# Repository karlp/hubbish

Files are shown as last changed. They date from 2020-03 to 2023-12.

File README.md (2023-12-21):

## Hubbish is not rubbish.

Hubbish is a USB 2.0 HS hub.  And?  It has per port power switching and overrcurrent shutoff.
And? It is designed for cascading, with 6 ports for user devices on the front, and ports
on each side for directly plugging together.  And? That's it.

## but why.gif?

Per port power switching was a goal.  Also, "this should be really simple!"
Also, to make the physical layout sensible for the desired use case.  Initially, this
project was conceived to be part of regression testing the USB stack for
[libopencm3](http://www.libopencm3.org).  The _minimal_ test setup there required 17
USB devices.  This is also why the ports are paired.  It's setup to have one port
for the DUT and one for the test driver.  They are otherwise completely independent.

That's all folks!

## Design goals
Cheap as shit, but fully functional. So, cheapest china compatible parts for everything,
but to avoid running into hub depth limits, and make config simpler, still using a
7 port hub, not attempting to cascade 4 port hubs.  Given that the original design goal requires
3 stacked hubs for 18 test ports, caascading hubs internally was not appealing.

Still, doing usb-hs on 2 layers requires fat traces and isolation to do properly, so this
setup is currently targetting jlcpcb's cheap as shit 4 layer 2313 stackup.

Oh, and design it to actually go in a case.

## Origins
This project was split out from the [libopencm3-tests](http://github.com/karlp/libopencm3-tests)
repository when it became apparent that it was it's own monster.

## Versions
### "r4" r2022-12
#### Status
Only on paper, mostly, uses a proper matched pair to "correctly" implement the auto vbus/5v switchiver. (I misunderstood the use of the matched pair, and just used two discrete transistors in overzealous BOM optimization.
TBD: fixes the pwoer good indicator on the main supply as well?
Still need to work on the "local power" portion a bit more fully? (or double check it?)

### "r3" r2022-10
#### Improvements
After a long hiatus, I decided to get back to it, and not even bother assembling the r2 boards I had gotten back.  I had already found some errors, which I can't remember entirely right now, so we just moved forward to r3:
This has a very overhauled BOM, to match JLC's assembly service, rather than just something to assemble myself by hand.
Some footprints change to suit this as well.

#### Status
This was built and assembled by JLC.  It works ok. It doesn't switch between bus powered and self powered very well, iirc.  The hub's "local power" flag isn't handled properly, and that's just my error.  The board still uses optional A-male or B-micro for the upstream USB connection, and "obviously" that should all be PD and type-C these days :)  maybe one day...
Finally, the dual colour leds chosen aren't really very good at showing two colours for low speed / full speed / high speed, particular the difference between FS and HS, which is the more interesting one.  Should revisit that, but I had enough on with this revision to not do more. The "Power Good" LED for the onboard DCDC supply doesn't work properly either, again, my error,  but not really critical.  Finally, the polarity protection FET is only rated to Vgs of 30V.  It's suggested (rightly) that this is really pushing it for a 24V design, and I should look for a better option there.

But, the 40W supply works! This is the biggest DCDC supply I'd ever made myself. (FIXME - add the picture of all the usb load testers plugged in) And not just works, it works and keeps cool, and you can deliver all that power to all 7 downstream ports, up to the limit of each of the load switches.

This design also just decided that programming the EEPROM was the _right_ thing to do, as it also lets you arrange the LEDs nicely to match the ports, and provide proper serial numbers, which are also an important part of a big cascaded port power switching design. [generatei2c.py] is a python script that generates commands for use with i2cutils to program the eeprom via the header.  I used the [i2c_tools example](https://github.com/espressif/esp-idf/tree/master/examples/peripherals/i2c/i2c_tools) on an ESP32 devboard to do this.  It's... very simplistic, but it's enough.

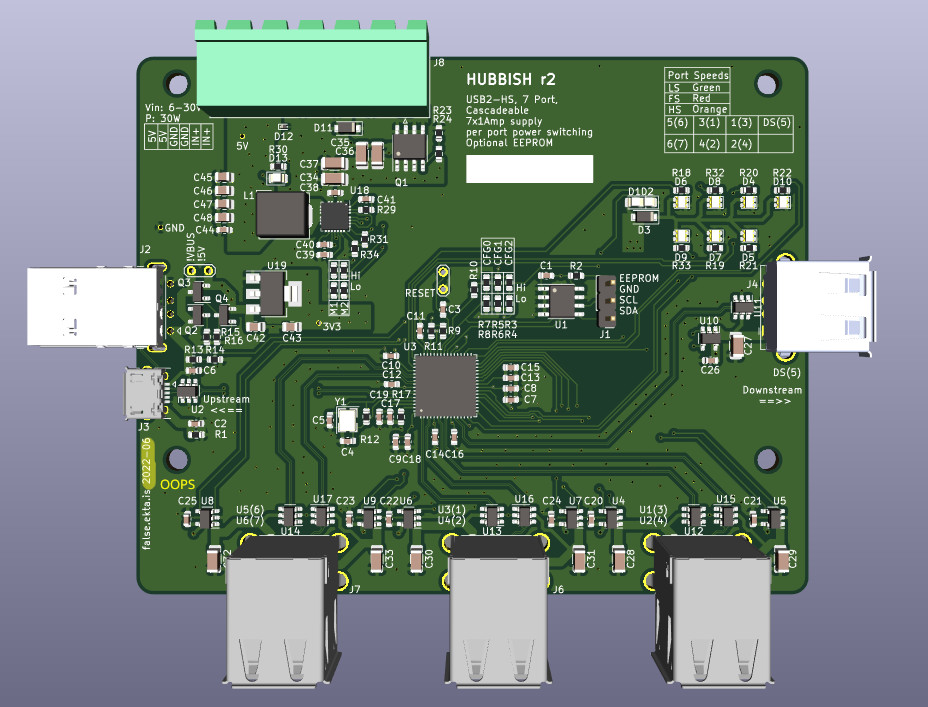
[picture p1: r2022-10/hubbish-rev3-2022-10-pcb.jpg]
r2022-10 board view
* 
* [Schematic-r3](r2022-10/hubbish-rev3-2022-10.pdf)
* Load testing all ports at once.  (I have thermal images, but have lost them... will have to retest)
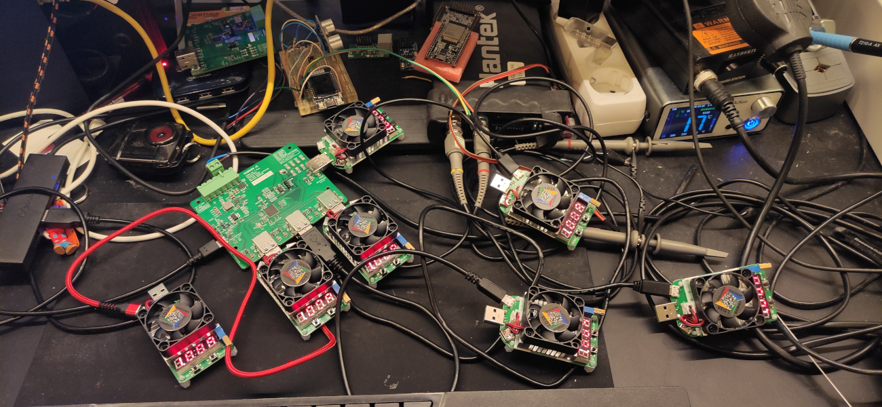
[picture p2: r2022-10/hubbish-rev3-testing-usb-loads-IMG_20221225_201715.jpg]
r2022-10-load-testing-view


### "r2" r2021-03  (lol, finished and ordered 2022-06)
#### Improvements:
Adds a 30-40ish Watt power supply.  Inductor is rated to 9A, regulator to 12A. Per port power switches are
still 1A nominal, so nominally 7x5x1 = 35W for the ports plus around .5x3.3 for the hub itself, or an extra say 2W.

Resizes to 100x80mm so cheaper manufacturing again.  We're no longer trying to find an off the shelf case.
Places like 3d craft cloud have gotten so cheap I'm going to just make a custom case and have it printed on demand.

What's it look like?
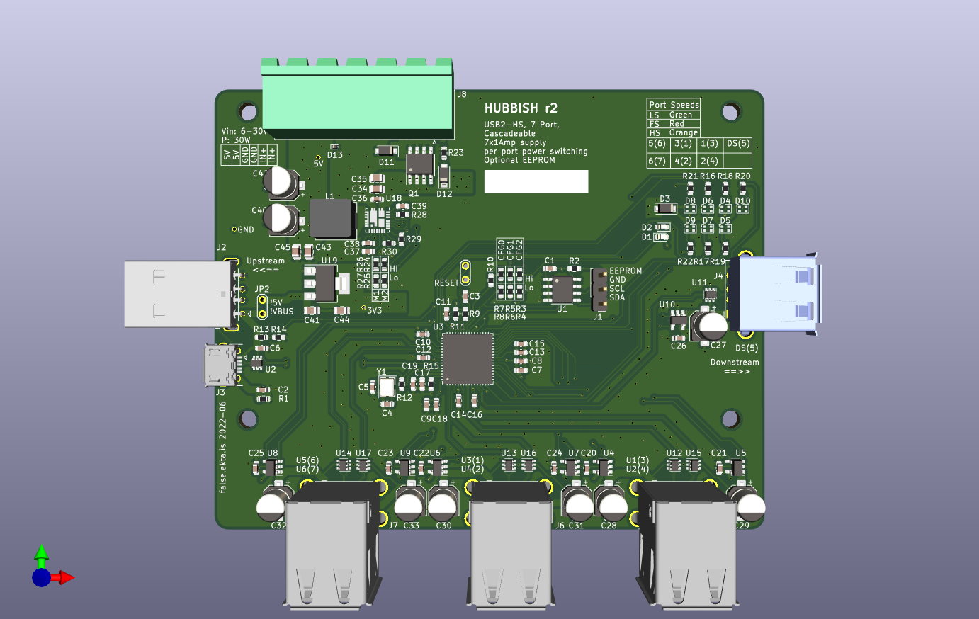
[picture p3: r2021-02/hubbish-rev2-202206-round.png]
r2022-06 board view


* [Schematic-r2](r2021-02/hubbish-rev2.pdf)

#### Bugs
This doesn't have ground connected for two caps on the 3v3 rail, and would have needed some bodge wires, but I seem to recall there being something else, to the point that I decided to not even bother assembling it, and just move on to a rev3, designed for JLC assembly.

### r2020-03
What's it look like?
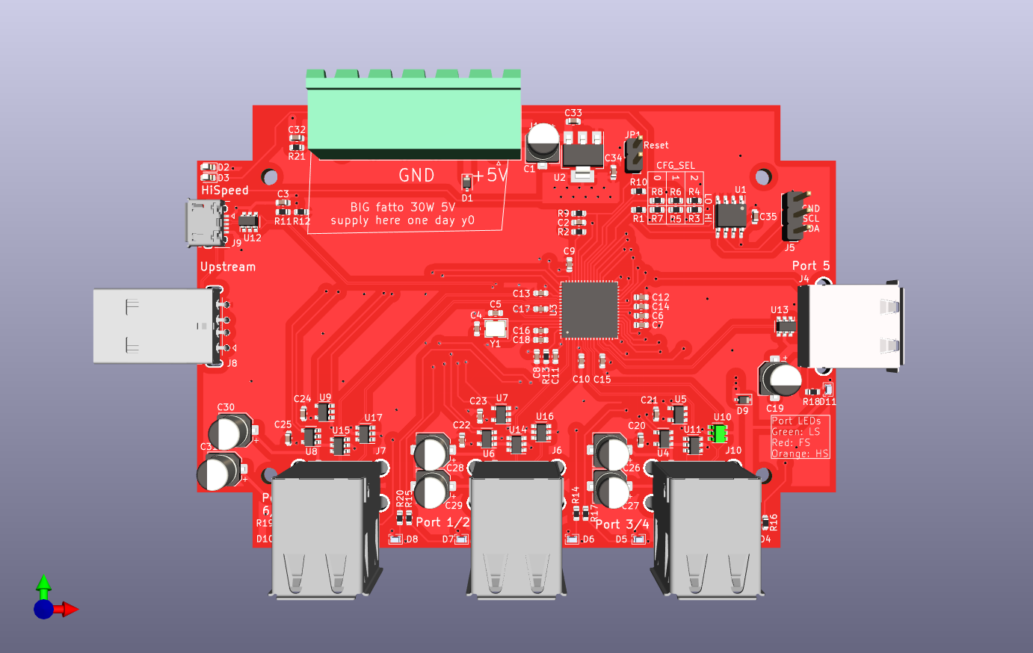
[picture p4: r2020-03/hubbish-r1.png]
r1 board view

* [Schematic-r1](r2020-03/usb-test-harness.pdf)

#### Bugs

1. Missing a serial resistor for the crystal.  Doesn't enumerate the hub without it.
1. Needs a jumper wire if yout want to actually run it as a bus powered hub for testing.
1. Port numbers are super wonky.
1. .... doesn't actually work?  I suspect I just have assembly issues, but...
1. Bigger than 100x100, which fits the Bud case nicely, and didn't matter when 4L was always just size based
   but now that jlc is doing 4L super cheap for under 100x100, this can be considered a bug
1. vertical (z axis) positioning of the usptream usb-a-male and downstream usb-a-female for chaining doesn't
   align properly.

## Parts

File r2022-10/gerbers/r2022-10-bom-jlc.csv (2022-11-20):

Comment | Designator | Footprint | JLCPCB Part #
100nF | C1,C2,C3,C8,C10,C11,C12,C14,C15,C16,C18,C19,C41,C44 | Capacitor_SMD:C_0603_1608Metric | C14663
33pF | C4,C5 | Capacitor_SMD:C_0603_1608Metric | C1663
1uF | C6,C7,C9,C13,C17,C20,C21,C22,C23,C24,C25,C26,C39,C40 | Capacitor_SMD:C_0603_1608Metric | C15849
100uF | C27,C28,C29,C30,C31,C32,C33 | Capacitor_SMD:C_1206_3216Metric | C15008
10uF/30+ | C34,C35,C36,C37 | Capacitor_SMD:C_1206_3216Metric | C13585
100nF/30+ | C38 | Capacitor_SMD:C_0603_1608Metric | C14663
10uF | C42,C43,C45,C46,C47,C48 | Capacitor_SMD:C_0805_2012Metric | C15850
HS1B | D1,D13 | LED_SMD:LED_0805_2012Metric | C84256
HS1B |  | LED_SMD:LED_0805_2012Metric | C84256
SM400x | D3 | Diode_SMD:D_SOD-123F | C64898
LTST-C195KGJRKT | D4,D5,D6,D7,D8,D9,D10 | LED_Dual:T1615_LiteOn_LTST_C195x | C125104
LTST-C195KGJRKT |  | LED_Dual:T1615_LiteOn_LTST_C195x | C125104
LTST-C195KGJRKT |  | LED_Dual:T1615_LiteOn_LTST_C195x | C125104
LTST-C195KGJRKT |  | LED_Dual:T1615_LiteOn_LTST_C195x | C125104
LTST-C195KGJRKT |  | LED_Dual:T1615_LiteOn_LTST_C195x | C125104
LTST-C195KGJRKT |  | LED_Dual:T1615_LiteOn_LTST_C195x | C125104
USB_B_Micro (up) | J3 | Connector_USB:USB_Micro-B_Amphenol_10118194-0001LF_Horizontal | C319164
USB_B_Micro (up) |  | Connector_USB:USB_Micro-B_Amphenol_10118194-0001LF_Horizontal | C319164
USB_B_Micro (up) |  | Connector_USB:USB_Micro-B_Amphenol_10118194-0001LF_Horizontal | C319164
USB_B_Micro (up) |  | Connector_USB:USB_Micro-B_Amphenol_10118194-0001LF_Horizontal | C319164
USB_B_Micro (up) |  | Connector_USB:USB_Micro-B_Amphenol_10118194-0001LF_Horizontal | C319164
1.5uH | L1 | Inductor_SMD:L_Chilisin_BMRx00060630 | C329386
HSM6115 | Q1 | Package_SO:SOIC-8_3.9x4.9mm_P1.27mm | C700986
S8550 | Q2,Q4 | Package_TO_SOT_SMD:SOT-23 | C105432
AO3401A | Q3 | Package_TO_SOT_SMD:SOT-23 | C15127
330 | R1,R10,R18,R19,R20,R21,R22,R30,R32,R33 | Resistor_SMD:R_0603_1608Metric | C23138
10k | R2,R4,R5,R7,R11,R15,R16,R23,R34 | Resistor_SMD:R_0603_1608Metric | C25804
100k | R9,R13,R14,R26 | Resistor_SMD:R_0603_1608Metric | C25803
1M | R12 | Resistor_SMD:R_0603_1608Metric | C22935
12k | R17 | Resistor_SMD:R_0603_1608Metric | C22790
20k | R24 | Resistor_SMD:R_0603_1608Metric | C4184
20k |  | Resistor_SMD:R_0603_1608Metric | C4184
510k | R28 | Resistor_SMD:R_0603_1608Metric | C23192
0 | R29 | Resistor_SMD:R_0603_1608Metric | C21189
75k | R31 | Resistor_SMD:R_0603_1608Metric | C23242
75k |  | Resistor_SMD:R_0603_1608Metric | C23242
2k i2c eeprom | U1 | Package_SO:SOIC-8_3.9x4.9mm_P1.27mm | C7562
NUP4202 | U2,U11,U12,U13,U14,U15,U16,U17 | Package_TO_SOT_SMD:SOT-23-6 | C85364
USB2517 | U3 | Package_DFN_QFN:QFN-64-1EP_9x9mm_P0.5mm_EP4.7x4.7mm_ThermalVias | C626667
APL3511C | U4,U5,U6,U7,U8,U9,U10 | Package_TO_SOT_SMD:SOT-23-5 | C211404
SiC437AED | U18 | Package_DFN_QFN:Vishay_MLP-44L_4x4 | C2071432
AMS1117-33 | U19 | Package_TO_SOT_SMD:SOT-223-3_TabPin2 | C6186
24MHz | Y1 | Crystal:Crystal_SMD_3225-4Pin_3.2x2.5mm | C70590

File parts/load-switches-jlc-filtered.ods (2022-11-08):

Part | jlc basic | jlc extended | enable level | overcurrent | iset | max I | package | pincompat | lcsc number | jlc price | notes
AIC6163-1GV5TR | no | yes | high | low | no | 1 | Sot23-5 | no
AP22802AW5-7 | no | yes | high | low | no | 2 | Sot23-5 | yes | C211404 | 0.166
APL3512ABI-TRG | no | yes | high | no | no | 2 | So23-5
APL3553ABI-TRG | no | yes | high | low | no | 2 | Sot23-5 | yes | C691406 | 0.229
bd2232G | no | yes | high | low | no | 1.3 | ssop5 | not at all | C308588
bd2233g | no |  | low | low | no | 1.3 | ssop5
DIO7002AST5 | no | yes | high | no | yes | 2.5 | Sot23-4
DIO7003HDST5 | no | yes | high | low | no | 1.5 | Sot23-5 | yes | C403841 | 0.218
DIO7003LBST5 | no | yes | low | low | no | 0.7 | Sot23-5
lp5208b5 | no | yes | high | no | no | 1.2 | Sot23-5
LPW5209AB5F | no | yes | high | no | yes | 2.1 | Sot23-5
max40200 | no | yes | high | no | no | 1.2 | Sot23-5 | no
MT9700 | no | yes | high | no | yes | 2 | Sot23-5
nct3521 | no | yes | high | no | no | 2 | Sot23-5
Ry2121 | no | yes | high | no | yes | 2 | Sot23-5 |  |  | 0.074 | (very cheap though)
SGM2554AYN5G/TR | no | yes | high | no | no | 2 | Sot23-5
SIP32431DR3-T1GE3 | no | yes | high | no | no | 1.2 | Sc70-6
st890 | no | yes | low | low | yes | 1.2 | so8
sy6280aaac | no | yes | high | no | yes | 2 | Sot23-5
sy6280aac | no | yes | high | no | yes | 2 | Sot23-5
sy6288c3aac | no | yes | high | low | no | 1.5 | Sot23-5 | yes | C207612 | 0.201
sy6288caac | no | yes | high | low | no | 2 | Sot23-5 | yes | C111830 | 0.167
TMI6262AL | no | yes | low | no | yes | 2.4
TPS2051BDBVR | no | yes | high | low | no | 0.5 | Sot23-5 | yes |  | 0.385
TPS2065CDBVR | no | yes | high | low | no | 1 | Sot23-5 | yes | C353882 | 0.609
TPS2065DBVR | no | yes | high | low | no | 1 | Sot23-5 | yes | C133792 | 0.935 | more expensive? Lower rdsON
TPS2069CDBVR | no | yes | high | low | no | 1.5 | Sot23-5 | yes | C181752 | 0.395 | very good stock
TPS22810DBVR | no | yes | high | no | no | 2 | Sot-23-6
tps2553dbvr | no | yes | high | low | yes | 1.5 | Sot-23-6 | no | C55266
Lp5209b5f-21 | no | yes | high | no | yes | 2.1 | Sot23-5 |  | C517266 | 0.124
SD00HA | no | yes | high | no | yes | 2 | Sot23-5

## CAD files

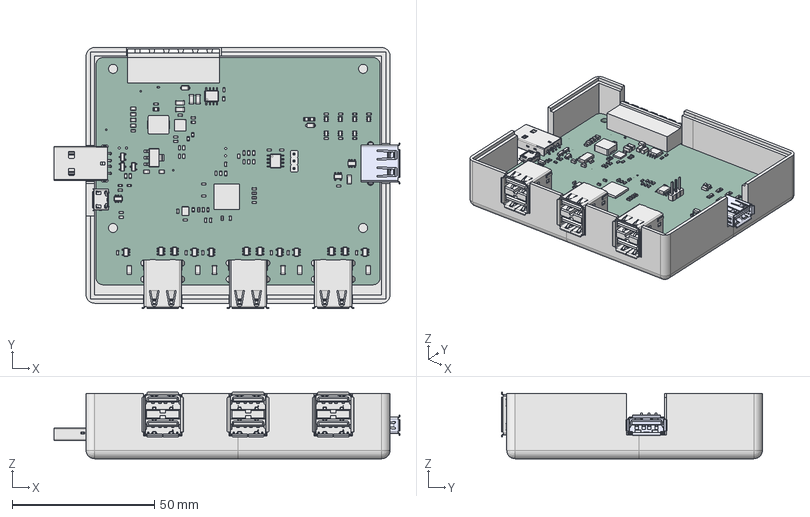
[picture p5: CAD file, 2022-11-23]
cases/hubbish-r3-202211-5.FCStd
121.8 x 91.8 x 23.4 mm
lower2
r2022-10 PCB

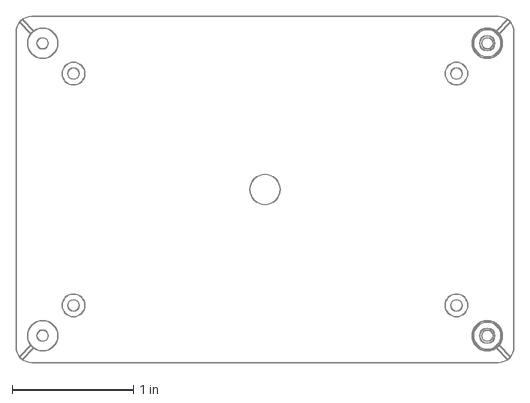
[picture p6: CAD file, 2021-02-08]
parts/enclosures/bud-pcb-guide.dxf
4.11 x 2.86 in

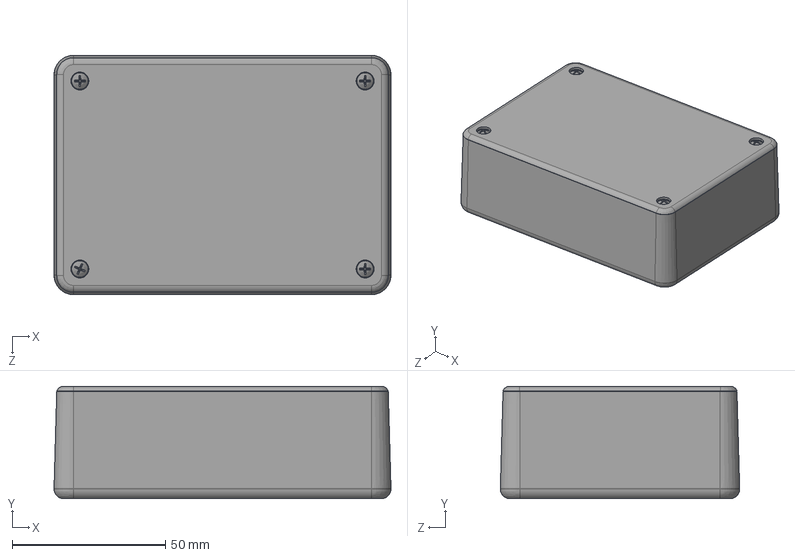
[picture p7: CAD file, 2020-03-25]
parts/enclosures/bud-CU-388.STEP
110.0 x 36.7 x 78.1 mm
387-SCR x 4
388-B
388-C

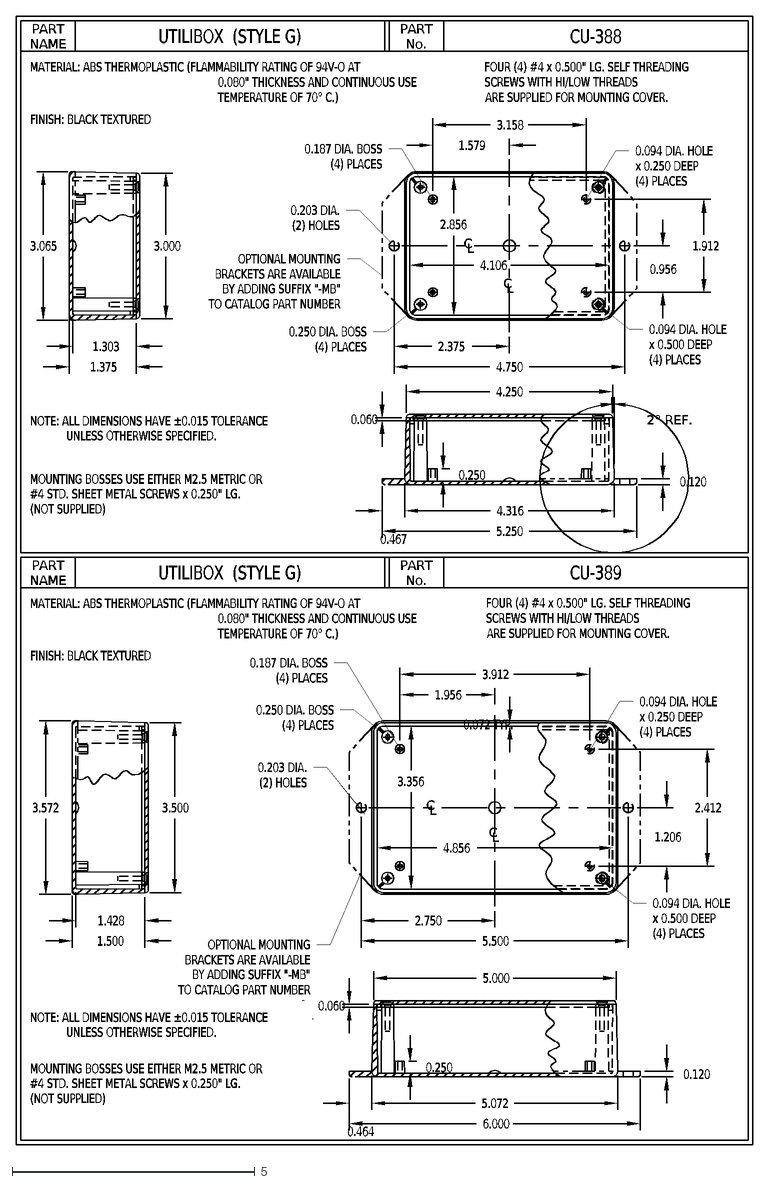
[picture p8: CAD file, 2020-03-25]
parts/enclosures/bud-hb388.dxf
FOUR (4) #4 x 0.500" LG. SELF THREADING
SCREWS WITH HI/LOW THREADS
%%@
%%!
ARE SUPPLIED FOR MOUNTING COVER.
NAME
PART
No.
UTILIBOX (STYLE G)
CU-388
MATERIAL: ABS THERMOPLASTIC (FLAMMABILITY RATING OF 94V-O AT
0.080" THICKNESS AND CONTINUOUS USE
TEMPERATURE OF 70° C.)
FINISH: BLACK TEXTURED
CU-389
0.060
4.250
3.000
1.303
1.375
3.065
1.579
3.158
C
L
0.094 DIA. HOLE
x 0.250 DEEP
(4) PLACES
0.187 DIA. BOSS
4.316
0.956
1.912
0.250
0.120
5.250
0.467
0.203 DIA.
(2) HOLES
4.750
2.375
OPTIONAL MOUNTING
BRACKETS ARE AVAILABLE
BY ADDING SUFFIX "-MB"
TO CATALOG PART NUMBER
x 0.500 DEEP
0.250 DIA. BOSS
4.106
2.856
2° REF.
5.000
0.072 TYP.
3.500
1.428
1.500
5.072
3.572
1.206
2.412
1.956
3.912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

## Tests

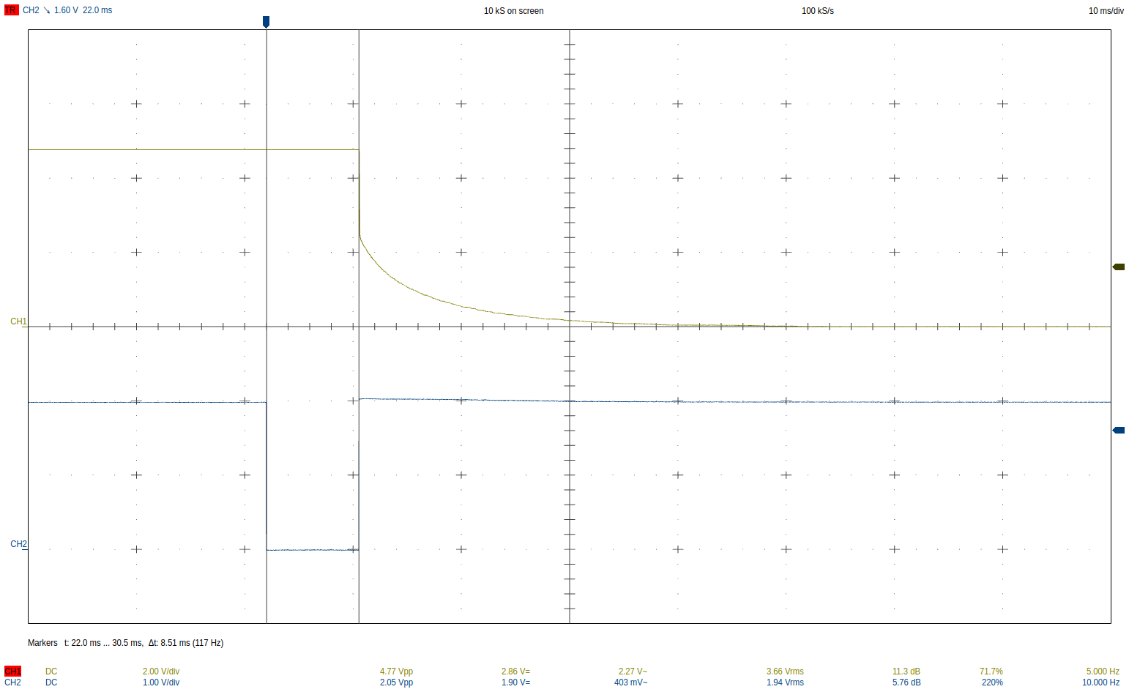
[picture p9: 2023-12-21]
testing/20221206_22414-vout-vs-flag-ocp.png

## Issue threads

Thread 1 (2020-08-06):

doesn't support self powered

karlp, 2020-08-06:
vbus is sensed, but that's it, set it up as self powered only for some reason

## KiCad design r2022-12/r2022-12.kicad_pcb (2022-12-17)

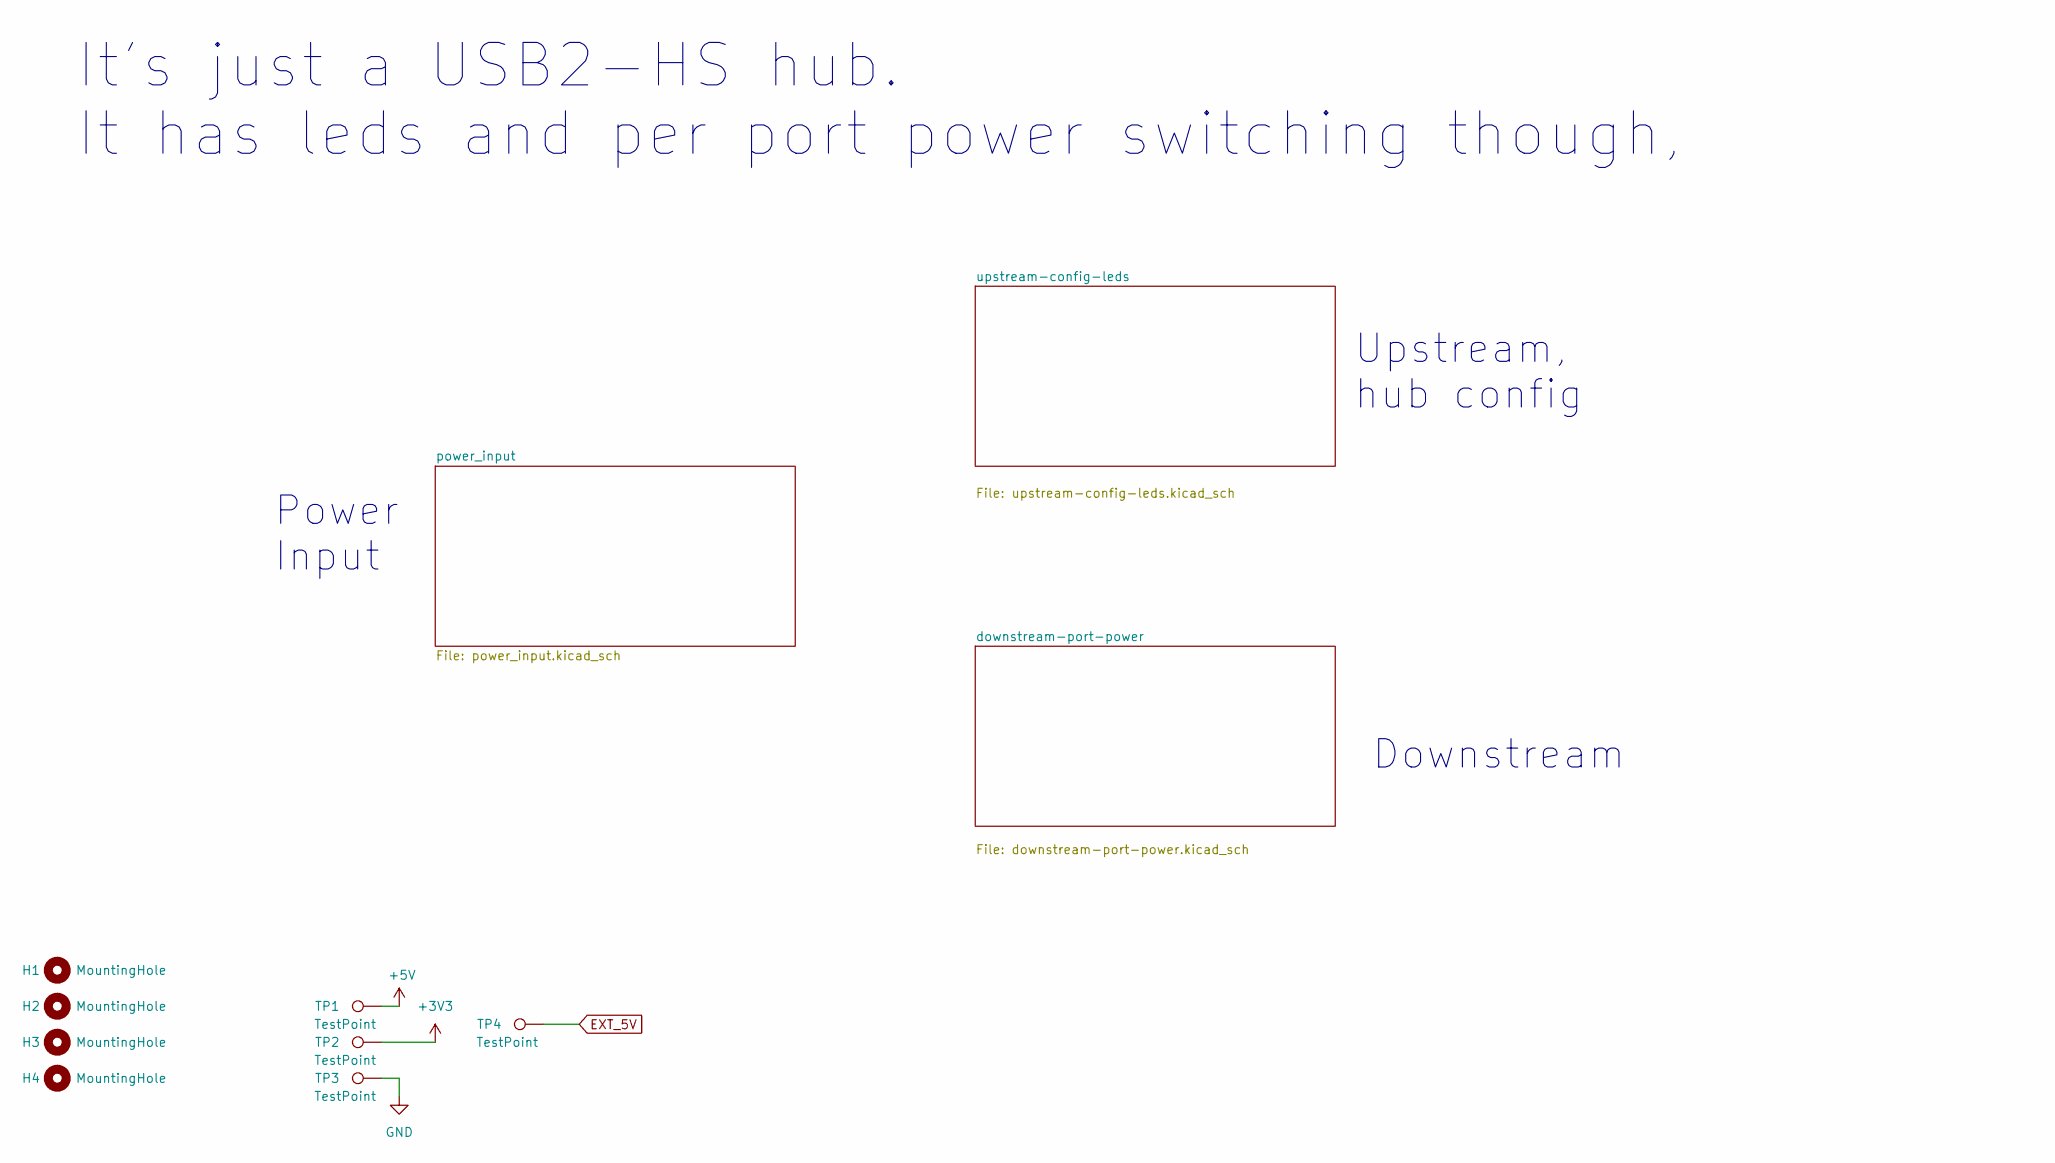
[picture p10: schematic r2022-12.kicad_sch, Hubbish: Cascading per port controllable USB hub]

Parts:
H1, H2, H3, H4: MountingHole; MountingHole_3.2mm_M3
TP1, TP2, TP3, TP4: TestPoint; TestPoint_Plated_Hole_0.6_D0.8mm

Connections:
+3V3: TP2.1; also elsewhere on the board
+5V: TP1.1; also elsewhere on the board
EXT_5V: TP4.1; also elsewhere on the board
GND: TP3.1; also elsewhere on the board

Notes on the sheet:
Upstream, hub config
Downstream
Power Input
It's just a USB2-HS hub. It has leds and per port power switching though,

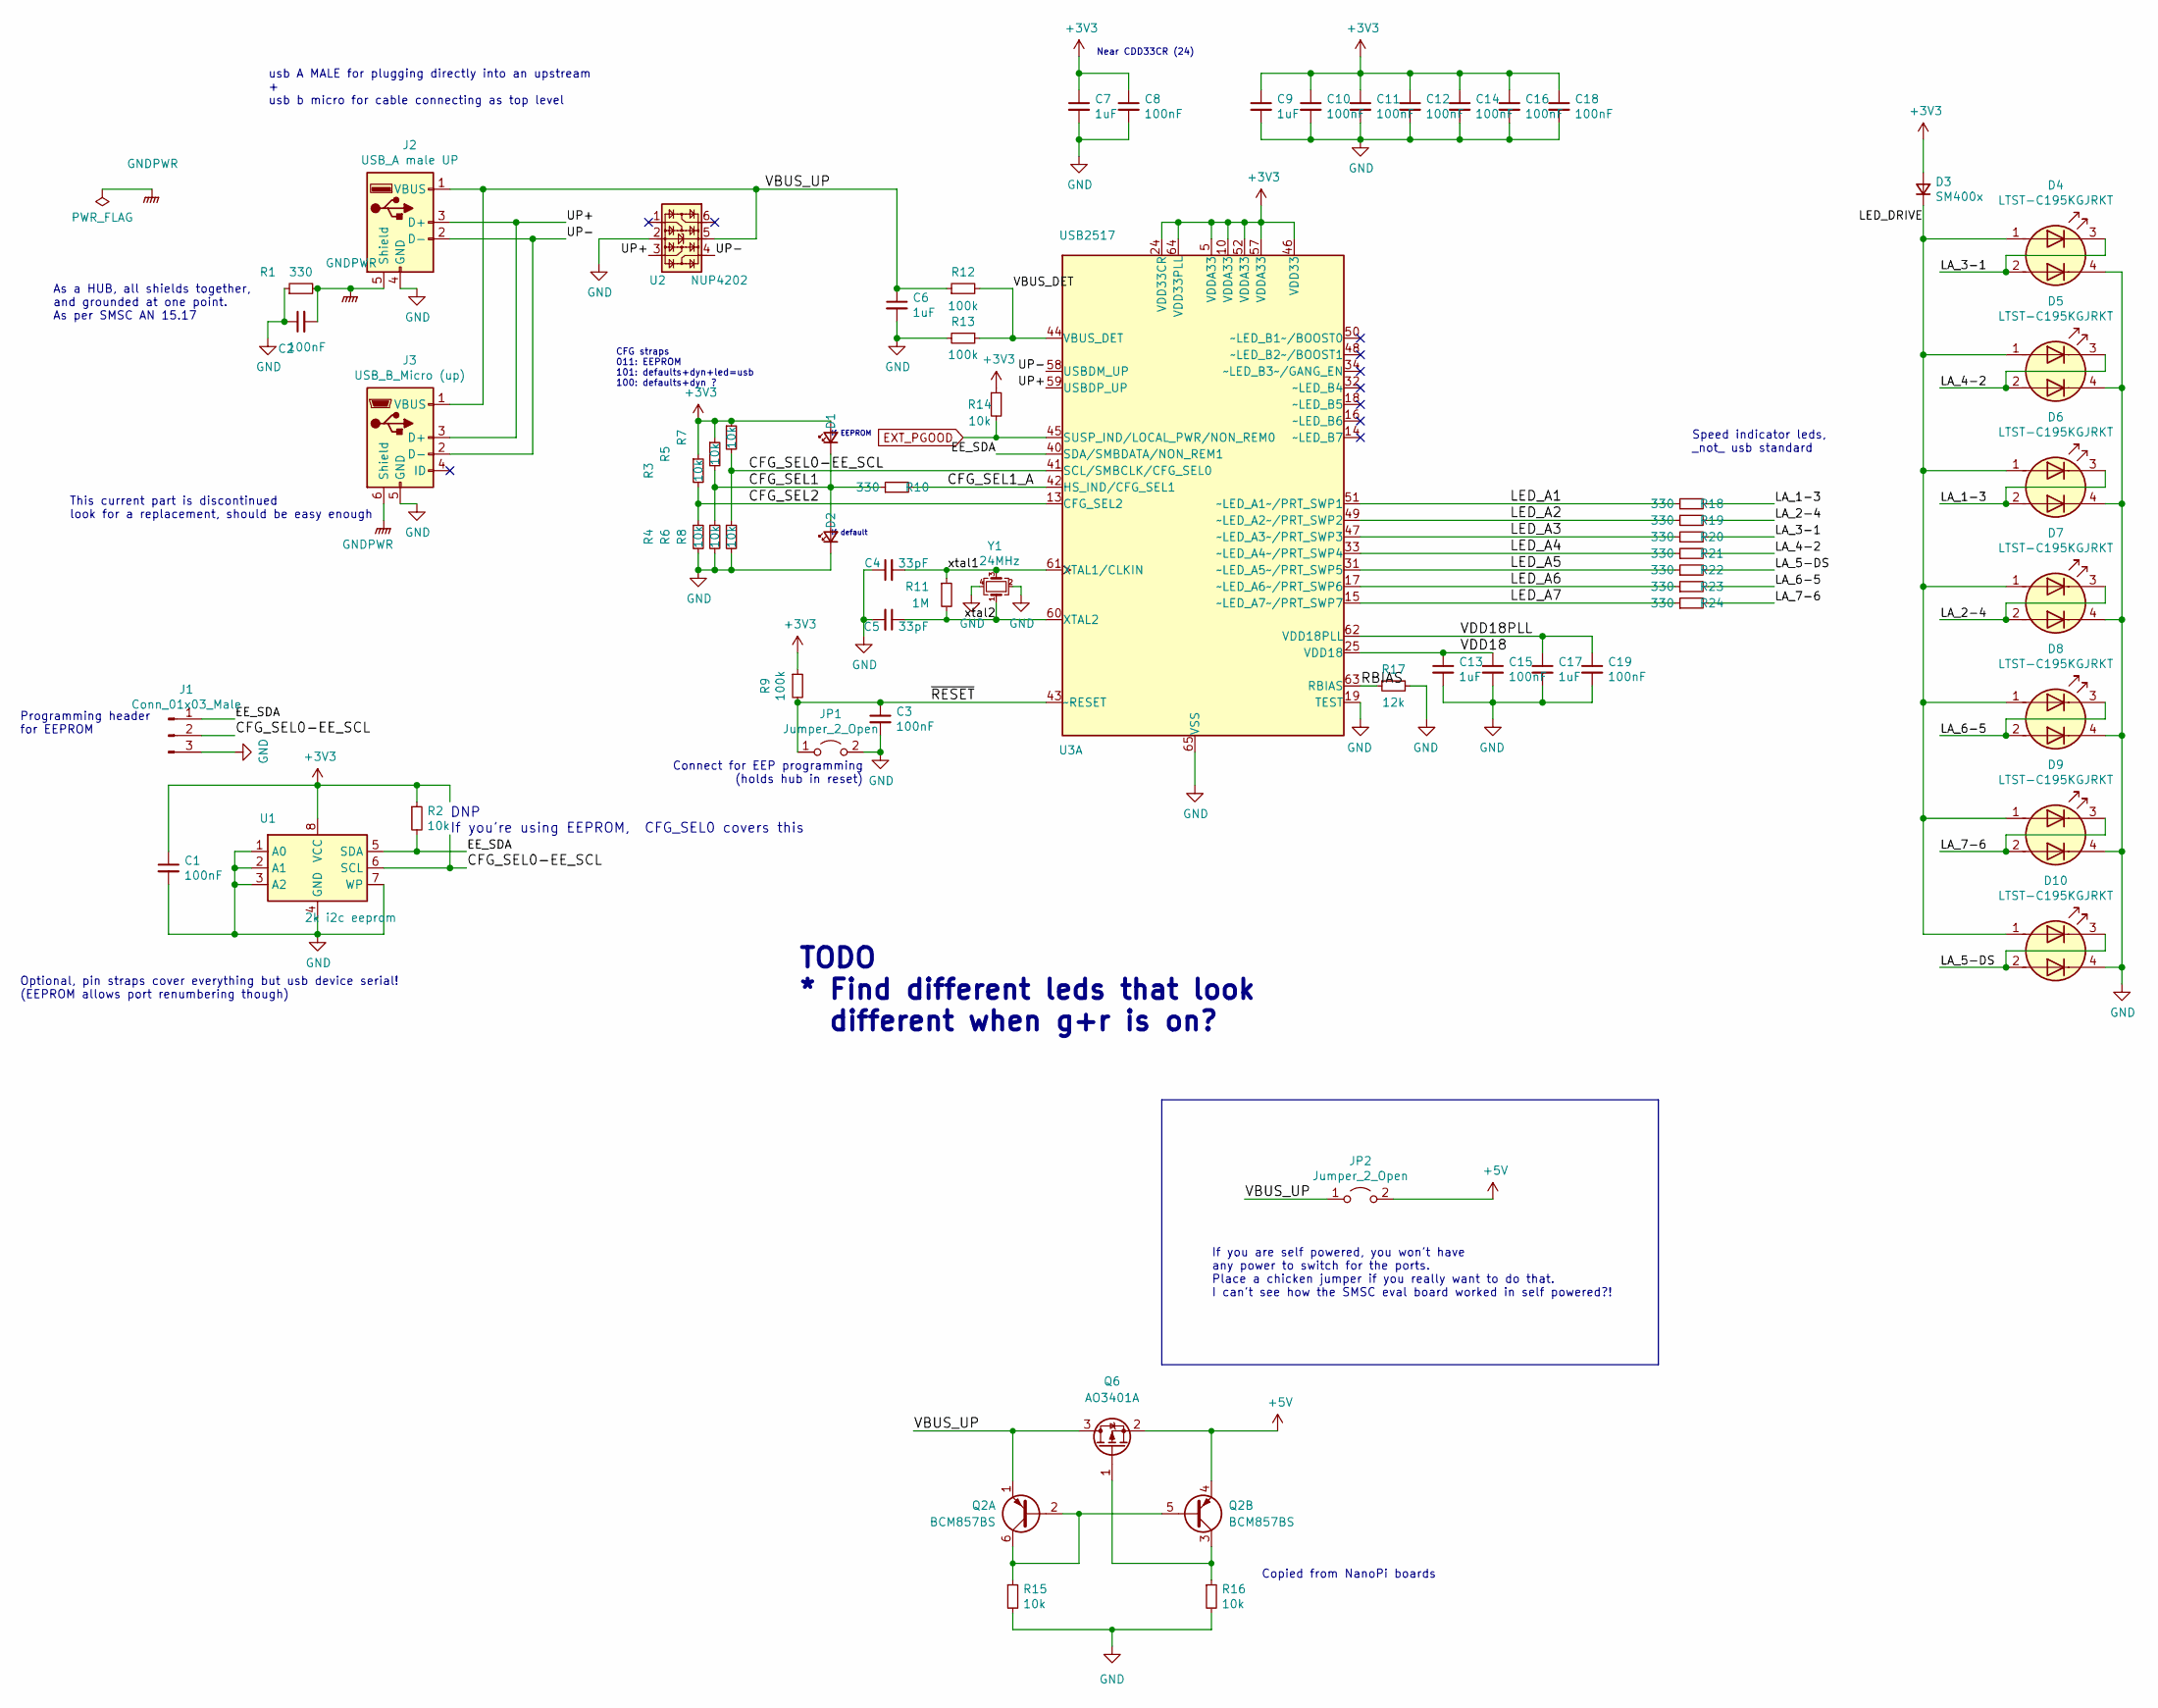
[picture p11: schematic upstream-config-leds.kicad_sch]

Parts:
C1, C2, C3, C8, C10, C11, C12, C14, C15, C16, C18, C19: 100nF; C_0603_1608Metric; MPN CC0603KRX7R9BB104; lcsc# C14663
C4, C5: 33pF; C_0603_1608Metric; MPN CL10C330JB8NNNC; jlc-basic 1
C6, C7, C9, C13, C17: 1uF; C_0603_1608Metric; MPN CL10A105KB8NNNC; jlc-basic 1
D1: HS1B; LED_0805_2012Metric; MPN NCD0805R1; jlc-basic 1
D2: HS1A; LED_0805_2012Metric; MPN NCD0805R1; jlc-basic 1
D3: SM400x; D_SOD-123F; MPN SM4007PL; jlc-basic 1
D4, D5, D6, D7, D8, D9, D10: LTST-C195KGJRKT; T1615_LiteOn_LTST_C195x; MPN LTST-C195KGJRKT; jlc-basic 0
J1: Conn_01x03_Male; PinHeader_1x03_P2.54mm_Vertical
J2: USB_A male UP; USB_A_Plug_SOFNG_USB-05; MPN SOFNG USB-05
J3: USB_B_Micro (up); USB_Micro-B_Amphenol_10118194-0001LF_Horizontal; MPN U254-051T-4BH23-S2B; jlc-basic 0
JP1, JP2: Jumper_2_Open; TestPoint_2Pads_Pitch2.54mm_Drill0.8mm
Q2: BCM857BS; SOT-363_SC-70-6; MPN BCM857BS-7-F; jlc-basic 0
Q6: AO3401A; SOT-23; MPN AO3401A; jlc-basic 1
R1, R10, R18, R19, R20, R21, R22, R23, R24: 330; R_0603_1608Metric; MPN 0603WAF3300T5E; jlc-basic 1
R2, R3, R4, R5, R6, R7, R8, R14, R15, R16: 10k; R_0603_1608Metric; MPN 0603WAF1002T5E; jlc-basic 1
R9, R12, R13: 100k; R_0603_1608Metric; MPN 0603WAF1003T5E; jlc-basic 1
R11: 1M; R_0603_1608Metric; MPN 0603WAF1004T5E; lcsc# C22935
R17: 12k; R_0603_1608Metric; MPN 0603WAF1202T5E; jlc-basic 1
U1: 2k i2c eeprom; SOIC-8_3.9x4.9mm_P1.27mm; MPN M24C02-WMN6TP; jlc-basic 1
U2: NUP4202; SOT-23-6; MPN SRV05-4-P-T7; jlc-basic 1
U3: USB2517; QFN-64-1EP_9x9mm_P0.5mm_EP4.7x4.7mm_ThermalVias; MPN USB2517I-JZX-TR; jlc-basic 0
Y1: 24MHz; Crystal_SMD_3225-4Pin_3.2x2.5mm; MPN X322524MOB4SI; jlc-basic 0

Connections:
+3V3: C1.1, C7.1, C8.1, C9.1, C10.1, C11.1, C12.1, C14.1, C16.1, C18.1, D1.2 (A), D3.2 (A), R2.1, R3.1, R5.1, R7.1, R9.1, R14.1, U1.8 (VCC), U3.5 (VDDA33), U3.10 (VDDA33), U3.24 (VDD33CR), U3.46 (VDD33), U3.52 (VDDA33), U3.57 (VDDA33), U3.64 (VDD33PLL); also elsewhere on the board
+5V: JP2.2 (B), Q2.4 (E2), Q6.2 (S); also elsewhere on the board
/upstream-config-leds/CFG_SEL0-EE_SCL: J1.2, R7.2, R8.1, U1.6 (SCL), U3.41 (SCL/SMBCLK/CFG_SEL0)
/upstream-config-leds/CFG_SEL1: D1.1 (K), D2.2 (A), R5.2, R6.1, R10.1
/upstream-config-leds/CFG_SEL1_A: R10.2, U3.42 (HS_IND/CFG_SEL1)
/upstream-config-leds/CFG_SEL2: R3.2, R4.1, U3.13 (CFG_SEL2)
/upstream-config-leds/EE_SDA: J1.1, R2.2, U1.5 (SDA), U3.40 (SDA/SMBDATA/NON_REM1)
/upstream-config-leds/LA_1-3: D6.2 (A2), D6.3 (K1), R18.2
/upstream-config-leds/LA_2-4: D7.2 (A2), D7.3 (K1), R19.2
/upstream-config-leds/LA_3-1: D4.2 (A2), D4.3 (K1), R20.2
/upstream-config-leds/LA_4-2: D5.2 (A2), D5.3 (K1), R21.2
/upstream-config-leds/LA_5-DS: D10.2 (A2), D10.3 (K1), R22.2
/upstream-config-leds/LA_6-5: D8.2 (A2), D8.3 (K1), R23.2
/upstream-config-leds/LA_7-6: D9.2 (A2), D9.3 (K1), R24.2
/upstream-config-leds/LED_A1: R18.1, U3.51 (~LED_A1~/PRT_SWP1)
/upstream-config-leds/LED_A2: R19.1, U3.49 (~LED_A2~/PRT_SWP2)
/upstream-config-leds/LED_A3: R20.1, U3.47 (~LED_A3~/PRT_SWP3)
/upstream-config-leds/LED_A4: R21.1, U3.33 (~LED_A4~/PRT_SWP4)
/upstream-config-leds/LED_A5: R22.1, U3.31 (~LED_A5~/PRT_SWP5)
/upstream-config-leds/LED_A6: R23.1, U3.17 (~LED_A6~/PRT_SWP6)
/upstream-config-leds/LED_A7: R24.1, U3.15 (~LED_A7~/PRT_SWP7)
/upstream-config-leds/LED_DRIVE: D3.1 (K), D4.1 (A1), D5.1 (A1), D6.1 (A1), D7.1 (A1), D8.1 (A1), D9.1 (A1), D10.1 (A1)
/upstream-config-leds/RBIAS: R17.1, U3.63 (RBIAS)
/upstream-config-leds/UP+: J2.3 (D+), J3.3 (D+), U2.3, U3.59 (USBDP_UP)
/upstream-config-leds/UP-: J2.2 (D-), J3.2 (D-), U2.4, U3.58 (USBDM_UP)
/upstream-config-leds/VBUS_DET: R12.2, R13.1, U3.44 (VBUS_DET)
/upstream-config-leds/VBUS_UP: C6.1, J2.1 (VBUS), J3.1 (VBUS), JP2.1 (A), Q2.1 (E1), Q6.3 (D), R12.1, U2.5
/upstream-config-leds/VDD18: C13.1, C15.1, U3.25 (VDD18)
/upstream-config-leds/VDD18PLL: C17.1, C19.1, U3.62 (VDD18PLL)
/upstream-config-leds/xtal1: C4.2, R11.1, U3.61 (XTAL1/CLKIN), Y1.3
/upstream-config-leds/xtal2: C5.1, R11.2, U3.60 (XTAL2), Y1.1
/upstream-config-leds/~RESET: C3.1, JP1.1 (A), R9.2, U3.43 (~RESET)
EXT_PGOOD: R14.2, U3.45 (SUSP_IND/LOCAL_PWR/NON_REM0); also elsewhere on the board
GND: C1.2, C2.1, C3.2, C4.1, C5.2, C6.2, C7.2, C8.2, C9.2, C10.2, C11.2, C12.2, C13.2, C14.2, C15.2, C16.2, C17.2, C18.2, C19.2, D2.1 (K), D4.4 (K2), D5.4 (K2), D6.4 (K2), D7.4 (K2), D8.4 (K2), D9.4 (K2), D10.4 (K2), J1.3, J2.4 (GND), J3.5 (GND), JP1.2 (B), R1.1, R4.2, R6.2, R8.2, R13.2, R15.2, R16.2, R17.2, U1.1 (A0), U1.2 (A1), U1.3 (A2), U1.4 (GND), U1.7 (WP), U2.2, U3.19 (TEST), U3.65 (VSS), Y1.2, Y1.4; also elsewhere on the board
GNDPWR: C2.2, J2.5 (Shield), J3.6 (Shield), R1.2; also elsewhere on the board
unnamed: Q2.3 (C2), Q6.1 (G), R16.1
unnamed: Q2.2 (B1), Q2.5 (B2), Q2.6 (C1), R15.1

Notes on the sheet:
If default
If EEPROM
usb A MALE for plugging directly into an upstream + usb b micro for cable connecting as top level
DNP If you're using EEPROM, CFG_SEL0 covers this
CFG straps 011: EEPROM 101: defaults+dyn+led=usb 100: defaults+dyn ?
Copied from NanoPi boards
TODO * Find different leds that look different when g+r is on?
Speed indicator leds, _not_ usb standard
If you are self powered, you won't have any power to switch for the ports. Place a chicken jumper if you really want to do that. I can't see how the SMSC eval board worked in self powered?!
Near CDD33CR (24)
As a HUB, all shields together, and grounded at one point. As per SMSC AN 15.17
Optional, pin straps cover everything but usb device serial! (EEPROM allows port renumbering though)
Programming header for EEPROM
Connect for EEP programming (holds hub in reset)
This current part is discontinued look for a replacement, should be easy enough

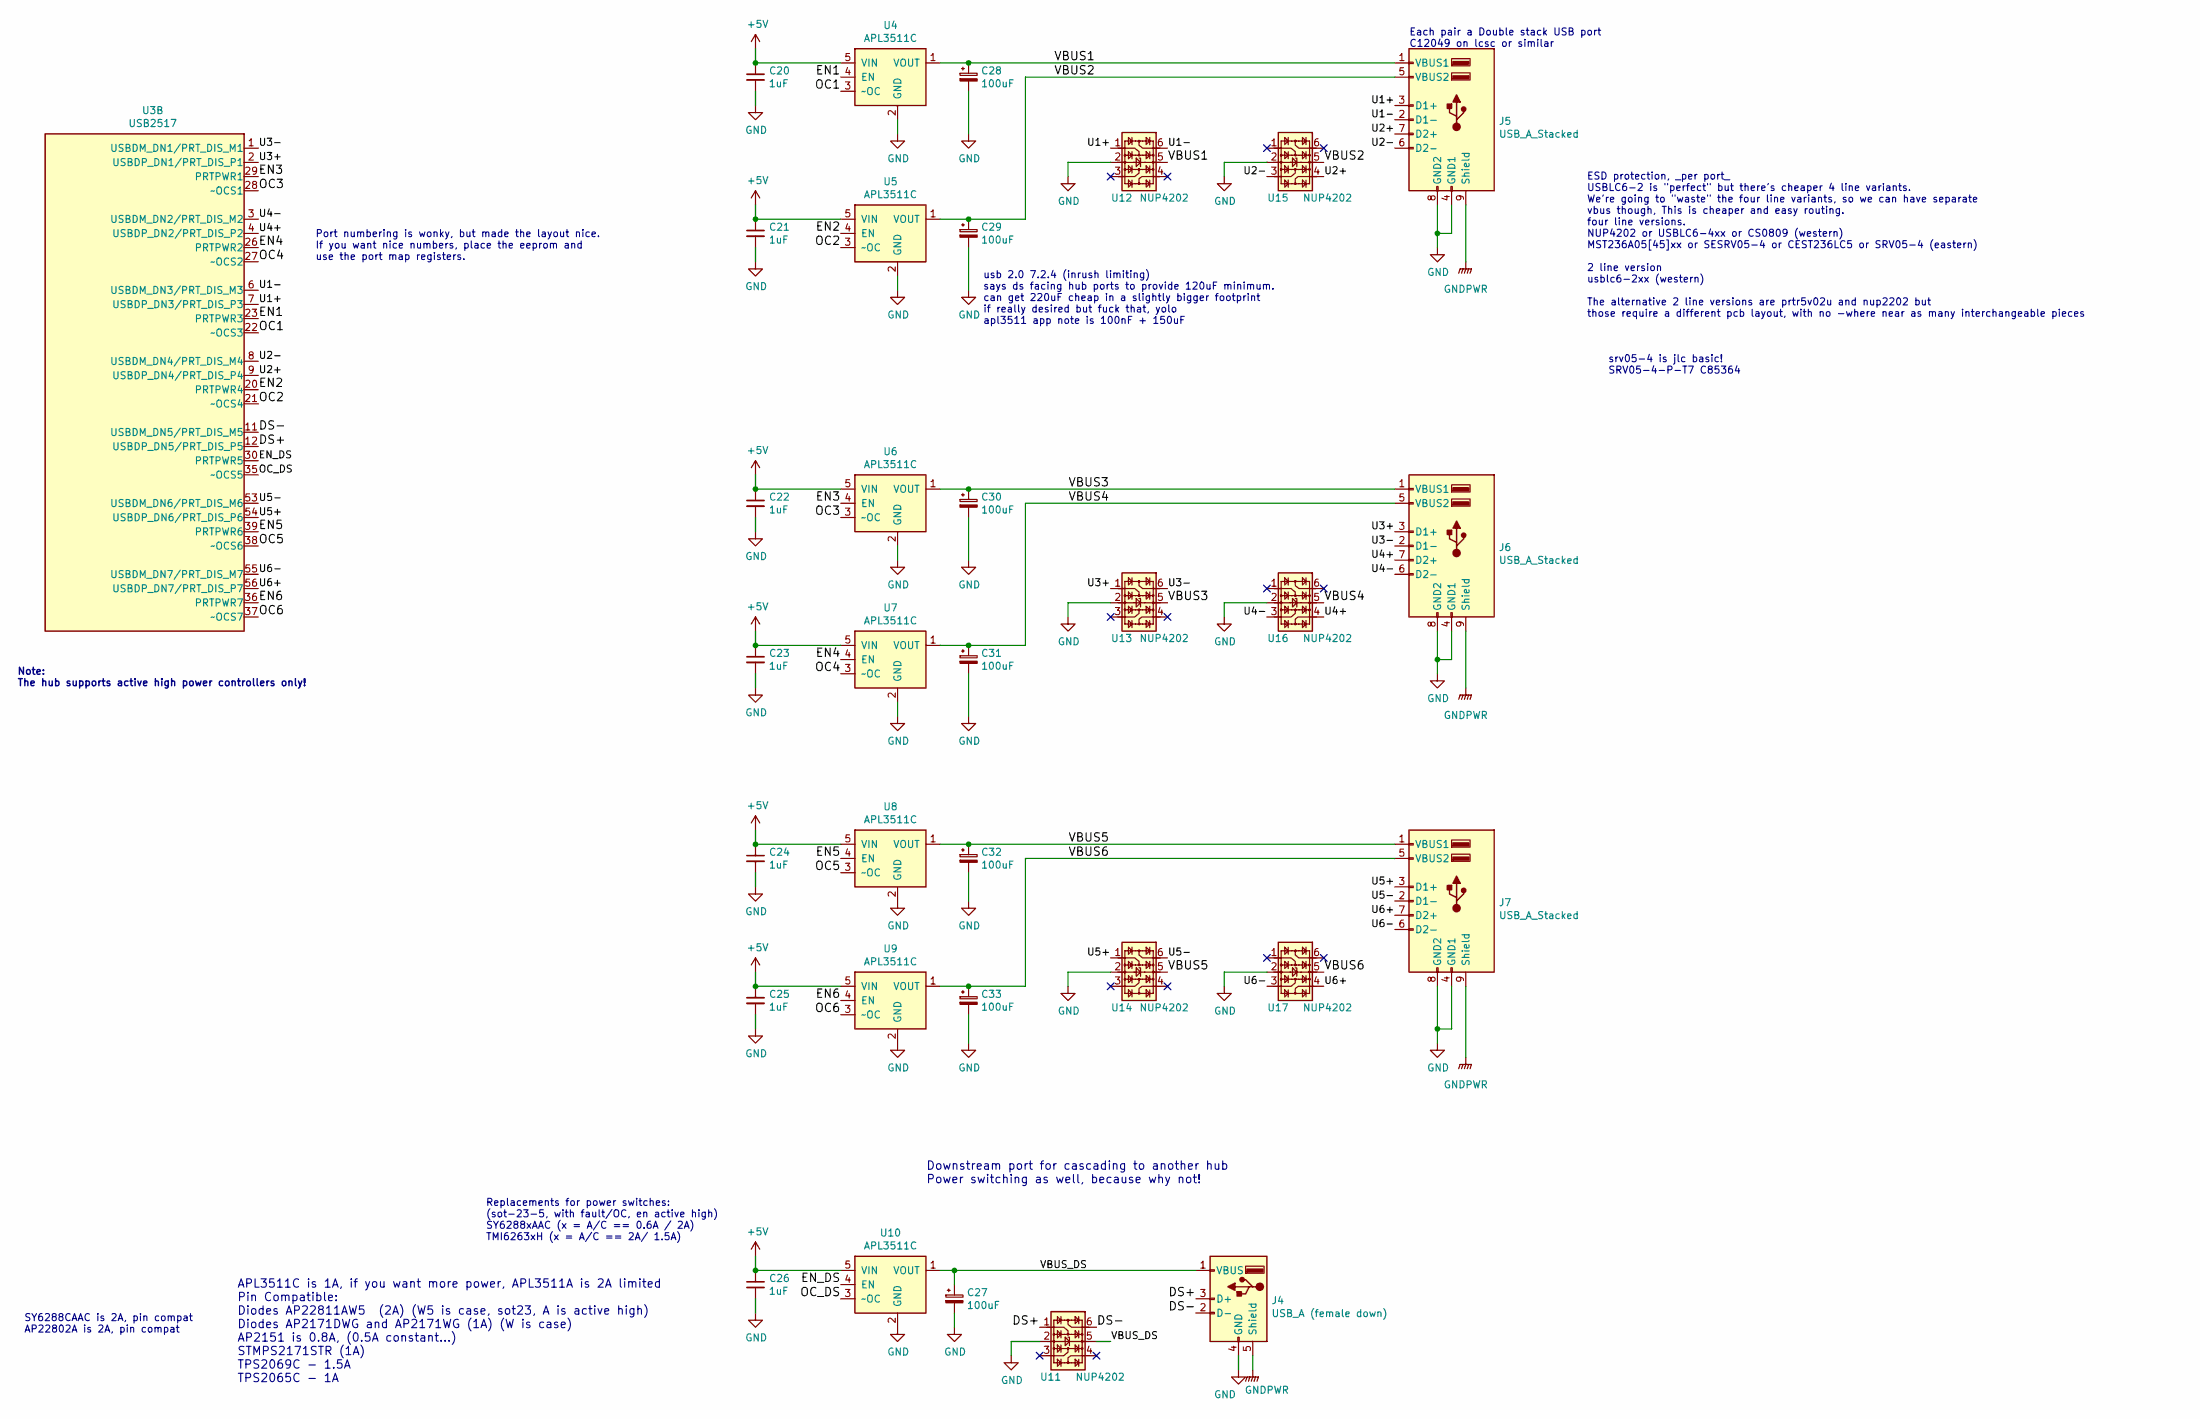
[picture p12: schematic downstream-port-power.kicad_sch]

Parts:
C20, C21, C22, C23, C24, C25, C26: 1uF; C_0603_1608Metric; MPN CL10A105KB8NNNC; jlc-basic 1
C27, C28, C29, C30, C31, C32, C33: 100uF; C_1206_3216Metric; MPN CL31A107MQHNNNE; jlc-basic 1
J4: USB_A (female down); USB_A_Stewart_SS-52100-001_Horizontal; MPN 902-141A1011D10100; jlc-basic 0
J5, J6, J7: USB_A_Stacked; USB_A_Wuerth_61400826021_Horizontal_Stacked; MPN 907-111A1012D10200; jlc-basic 0
U3: USB2517; QFN-64-1EP_9x9mm_P0.5mm_EP4.7x4.7mm_ThermalVias; MPN USB2517I-JZX-TR; jlc-basic 0
U4, U5, U6, U7, U8, U9, U10: APL3511C; SOT-23-5; MPN AP22802AW5-7; jlc-basic 0
U11, U12, U13, U14, U15, U16, U17: NUP4202; SOT-23-6; MPN SRV05-4-P-T7; jlc-basic 1

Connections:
+5V: C20.1, C21.1, C22.1, C23.1, C24.1, C25.1, C26.1, U4.5 (VIN), U5.5 (VIN), U6.5 (VIN), U7.5 (VIN), U8.5 (VIN), U9.5 (VIN), U10.5 (VIN); also elsewhere on the board
/downstream-port-power/DS+: J4.3 (D+), U3.12 (USBDP_DN5/PRT_DIS_P5), U11.1
/downstream-port-power/DS-: J4.2 (D-), U3.11 (USBDM_DN5/PRT_DIS_M5), U11.6
/downstream-port-power/EN1: U3.23 (PRTPWR3), U4.4 (EN)
/downstream-port-power/EN2: U3.20 (PRTPWR4), U5.4 (EN)
/downstream-port-power/EN3: U3.29 (PRTPWR1), U6.4 (EN)
/downstream-port-power/EN4: U3.26 (PRTPWR2), U7.4 (EN)
/downstream-port-power/EN5: U3.39 (PRTPWR6), U8.4 (EN)
/downstream-port-power/EN6: U3.36 (PRTPWR7), U9.4 (EN)
/downstream-port-power/EN_DS: U3.30 (PRTPWR5), U10.4 (EN)
/downstream-port-power/OC1: U3.22 (~OCS3), U4.3 (~OC)
/downstream-port-power/OC2: U3.21 (~OCS4), U5.3 (~OC)
/downstream-port-power/OC3: U3.28 (~OCS1), U6.3 (~OC)
/downstream-port-power/OC4: U3.27 (~OCS2), U7.3 (~OC)
/downstream-port-power/OC5: U3.38 (~OCS6), U8.3 (~OC)
/downstream-port-power/OC6: U3.37 (~OCS7), U9.3 (~OC)
/downstream-port-power/OC_DS: U3.35 (~OCS5), U10.3 (~OC)
/downstream-port-power/U1+: J5.3 (D1+), U3.7 (USBDP_DN3/PRT_DIS_P3), U12.1
/downstream-port-power/U1-: J5.2 (D1-), U3.6 (USBDM_DN3/PRT_DIS_M3), U12.6
/downstream-port-power/U2+: J5.7 (D2+), U3.9 (USBDP_DN4/PRT_DIS_P4), U15.4
/downstream-port-power/U2-: J5.6 (D2-), U3.8 (USBDM_DN4/PRT_DIS_M4), U15.3
/downstream-port-power/U3+: J6.3 (D1+), U3.2 (USBDP_DN1/PRT_DIS_P1), U13.1
/downstream-port-power/U3-: J6.2 (D1-), U3.1 (USBDM_DN1/PRT_DIS_M1), U13.6
/downstream-port-power/U4+: J6.7 (D2+), U3.4 (USBDP_DN2/PRT_DIS_P2), U16.4
/downstream-port-power/U4-: J6.6 (D2-), U3.3 (USBDM_DN2/PRT_DIS_M2), U16.3
/downstream-port-power/U5+: J7.3 (D1+), U3.54 (USBDP_DN6/PRT_DIS_P6), U14.1
/downstream-port-power/U5-: J7.2 (D1-), U3.53 (USBDM_DN6/PRT_DIS_M6), U14.6
/downstream-port-power/U6+: J7.7 (D2+), U3.56 (USBDP_DN7/PRT_DIS_P7), U17.4
/downstream-port-power/U6-: J7.6 (D2-), U3.55 (USBDM_DN7/PRT_DIS_M7), U17.3
/downstream-port-power/VBUS1: C28.1, J5.1 (VBUS1), U4.1 (VOUT), U12.5
/downstream-port-power/VBUS2: C29.1, J5.5 (VBUS2), U5.1 (VOUT), U15.5
/downstream-port-power/VBUS3: C30.1, J6.1 (VBUS1), U6.1 (VOUT), U13.5
/downstream-port-power/VBUS4: C31.1, J6.5 (VBUS2), U7.1 (VOUT), U16.5
/downstream-port-power/VBUS5: C32.1, J7.1 (VBUS1), U8.1 (VOUT), U14.5
/downstream-port-power/VBUS6: C33.1, J7.5 (VBUS2), U9.1 (VOUT), U17.5
/downstream-port-power/VBUS_DS: C27.1, J4.1 (VBUS), U10.1 (VOUT), U11.5
GND: C20.2, C21.2, C22.2, C23.2, C24.2, C25.2, C26.2, C27.2, C28.2, C29.2, C30.2, C31.2, C32.2, C33.2, J4.4 (GND), J5.4 (GND1), J5.8 (GND2), J6.4 (GND1), J6.8 (GND2), J7.4 (GND1), J7.8 (GND2), U4.2 (GND), U5.2 (GND), U6.2 (GND), U7.2 (GND), U8.2 (GND), U9.2 (GND), U10.2 (GND), U11.2, U12.2, U13.2, U14.2, U15.2, U16.2, U17.2; also elsewhere on the board
GNDPWR: J4.5 (Shield), J5.9 (Shield), J6.9 (Shield), J7.9 (Shield); also elsewhere on the board

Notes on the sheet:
Note: The hub supports active high power controllers only!
Downstream port for cascading to another hub Power switching as well, because why not!
srv05-4 is jlc basic! SRV05-4-P-T7 C85364
usb 2.0 7.2.4 (inrush limiting) says ds facing hub ports to provide 120uF minimum. can get 220uF cheap in a slightly bigger footprint if really desired but fuck that, yolo apl3511 app note is 100nF + 150uF
Each pair a Double stack USB port C12049 on lcsc or similar
Replacements for power switches: (sot-23-5, with fault/OC, en active high) SY6288xAAC (x = A/C == 0.6A / 2A) TMI6263xH (x = A/C == 2A/ 1.5A)
SY6288CAAC is 2A, pin compat AP22802A is 2A, pin compat
APL3511C is 1A, if you want more power, APL3511A is 2A limited Pin Compatible: Diodes AP22811AW5 (2A) (W5 is case, sot23, A is active high) Diodes AP2171DWG and AP2171WG (1A) (W is case) AP2151 is 0.8A, (0.5A constant...) STMPS2171STR (1A) TPS2069C - 1.5A TPS2065C - 1A
ESD protection, _per port_ USBLC6-2 is "perfect" but there's cheaper 4 line variants. We're going to "waste" the four line variants, so we can have separate vbus though, This is cheaper and easy routing. four line versions. NUP4202 or USBLC6-4xx or CS0809 (western) MST236A05[45]xx or SESRV05-4 or C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
Port numbering is wonky, but made the layout nice. If you want nice numbers, place the eeprom and use the port map registers.

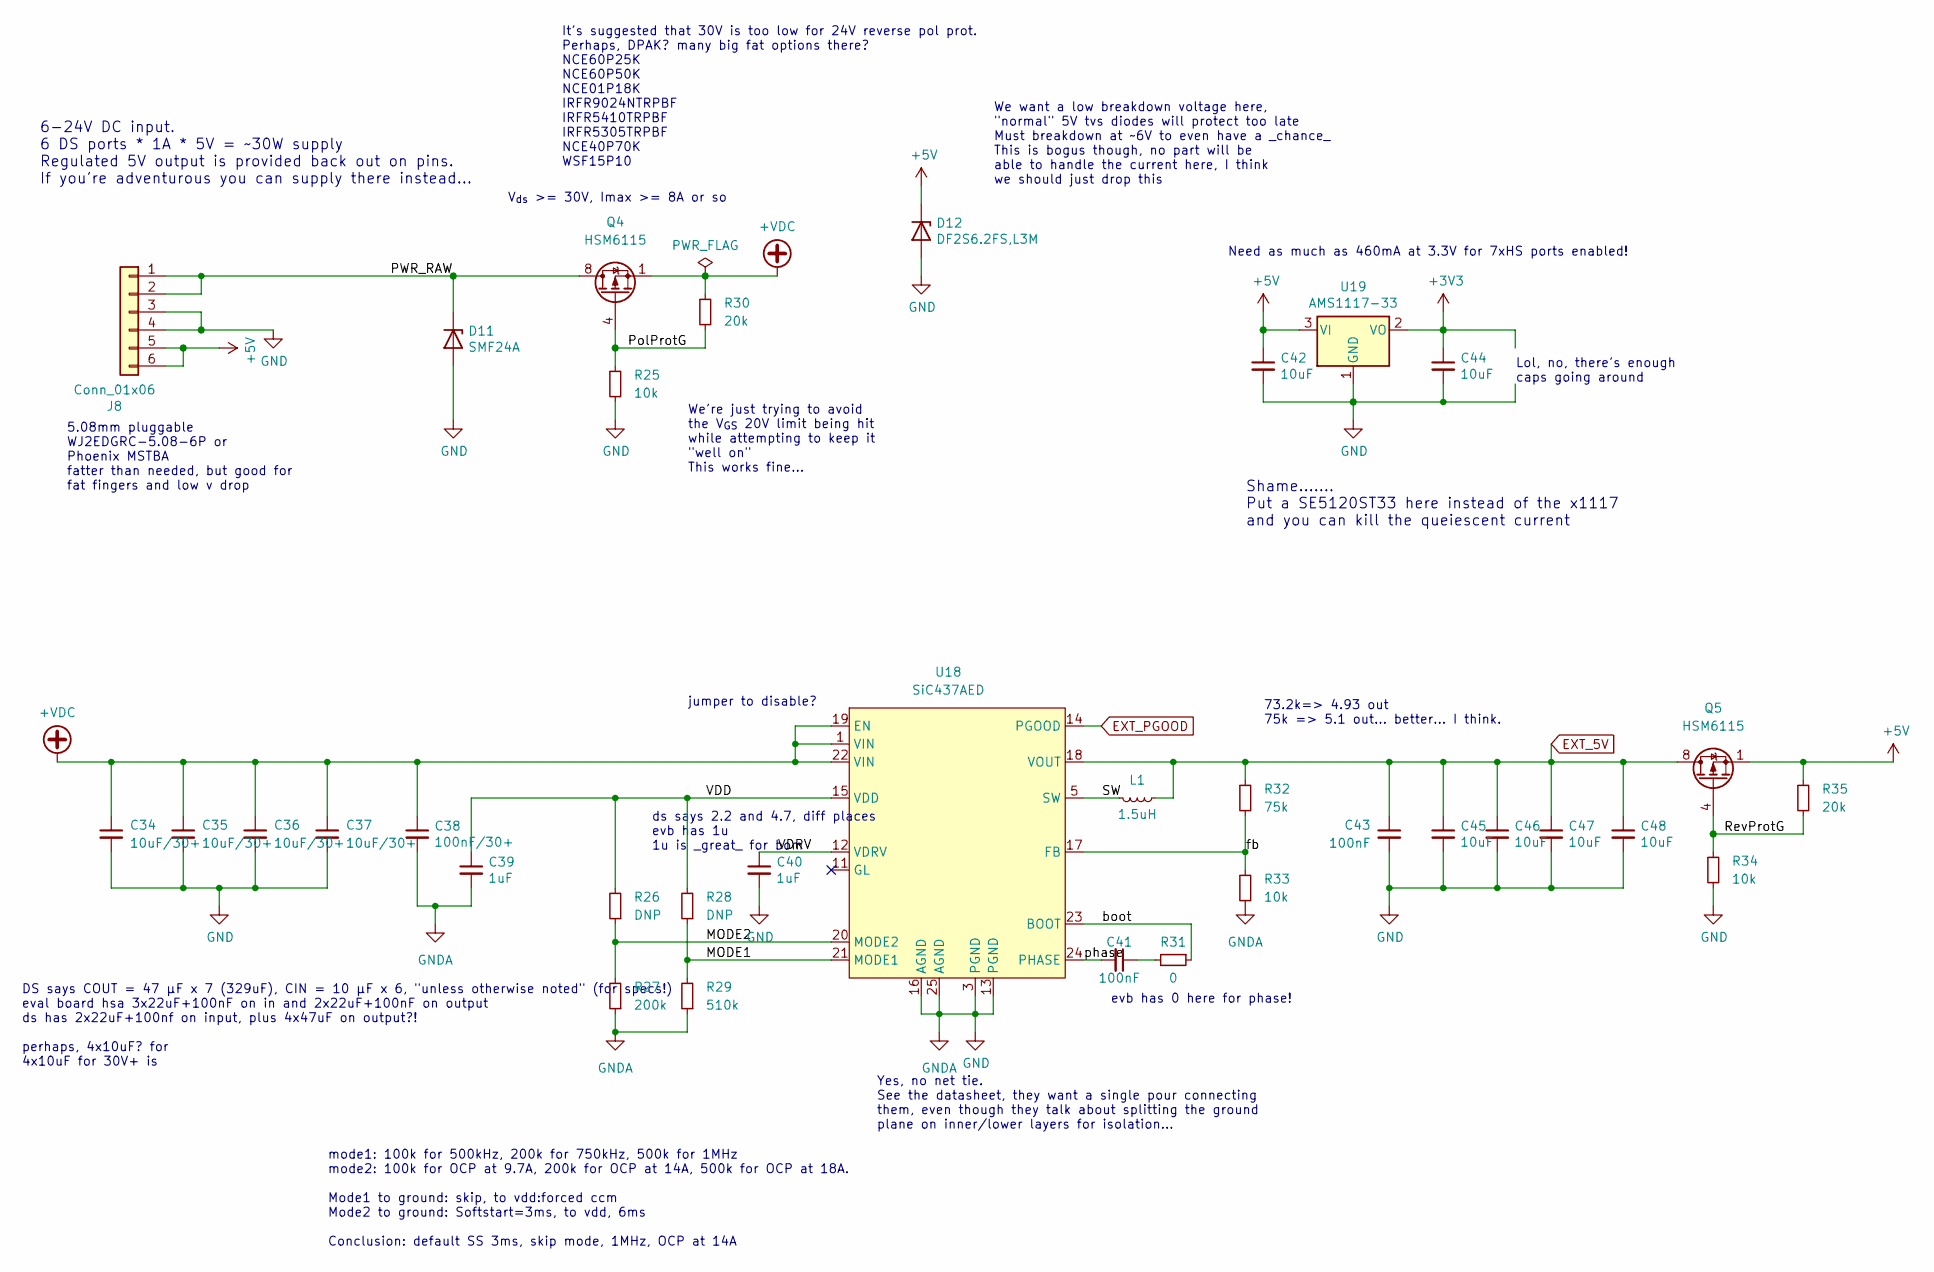
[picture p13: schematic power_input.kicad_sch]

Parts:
C34, C35, C36, C37: 10uF/30+; C_1206_3216Metric; MPN CL31A106KBHNNNE; lcsc# C13585
C38: 100nF/30+; C_0603_1608Metric; MPN CC0603KRX7R9BB104; lcsc# C14663
C39, C40: 1uF; C_0603_1608Metric; MPN CL10A105KB8NNNC; jlc-basic 1
C41, C43: 100nF; C_0603_1608Metric; MPN CC0603KRX7R9BB104; lcsc# C14663
C42, C44, C45, C46, C47, C48: 10uF; C_0805_2012Metric; MPN CL21A106KAYNNNE; lcsc# C15850
D11: SMF24A; D_SOD-123F; MPN SMF24A; jlc-basic 0
D12: DF2S6.2FS,L3M; D_SOD-923
J8: Conn_01x06; PhoenixContact_MSTBA_2,5_6-G-5,08_1x06_P5.08mm_Horizontal
L1: 1.5uH; L_Chilisin_BMRx00060630; MPN MHCI06030-1R5M-R8A; jlc-basic 0
Q4, Q5: HSM6115; SOIC-8_3.9x4.9mm_P1.27mm; MPN HSM6115; jlc-basic 0
R25, R33, R34: 10k; R_0603_1608Metric; MPN 0603WAF1002T5E; jlc-basic 1
R26, R28: DNP; R_0603_1608Metric
R27: 200k; R_0603_1608Metric; MPN 0603WAF2003T5E; jlc-basic 1
R29: 510k; R_0603_1608Metric; MPN 0603WAF5103T5E; lcsc# C23192
R30, R35: 20k; R_0603_1608Metric; MPN 0603WAF2002T5E; jlc-basic 1
R31: 0; R_0603_1608Metric; MPN 0603WAF0000T5E; jlc-basic 1
R32: 75k; R_0603_1608Metric; MPN 0603WAF7502T5E; jlc-basic 1
U18: SiC437AED; Vishay_MLP-44L_4x4; MPN SIC437AED-T1-GE3; jlc-basic 0
U19: AMS1117-33; SOT-223-3_TabPin2; MPN AMS1117-33; jlc-basic 1

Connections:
+3V3: C44.1, U19.2 (VO); also elsewhere on the board
+5V: C42.1, D12.1 (K), J8.5, J8.6, Q5.1 (S), Q5.2 (S), Q5.3 (S), R35.1, U19.3 (VI); also elsewhere on the board
+VDC: C34.1, C35.1, C36.1, C37.1, C38.1, Q4.1 (S), Q4.2 (S), Q4.3 (S), R30.1, U18.1 (VIN), U18.19 (EN), U18.22 (VIN)
/power_input/MODE1: R28.1, R29.2, U18.21 (MODE1)
/power_input/MODE2: R26.1, R27.2, U18.20 (MODE2)
/power_input/PWR_RAW: D11.1 (K), J8.1, J8.2, Q4.5 (D), Q4.6 (D), Q4.7 (D), Q4.8 (D)
/power_input/PolProtG: Q4.4 (G), R25.1, R30.2
/power_input/RevProtG: Q5.4 (G), R34.1, R35.2
/power_input/SW: L1.2, U18.5 (SW)
/power_input/VDD: C39.1, R26.2, R28.2, U18.15 (VDD)
/power_input/VDRV: C40.1, U18.12 (VDRV)
/power_input/boot: R31.1, U18.23 (BOOT)
/power_input/fb: R32.2, R33.1, U18.17 (FB)
/power_input/phase: C41.2, U18.24 (PHASE)
EXT_5V: C43.1, C45.1, C46.1, C47.1, C48.1, L1.1, Q5.5 (D), Q5.6 (D), Q5.7 (D), Q5.8 (D), R32.1, U18.18 (VOUT); also elsewhere on the board
EXT_PGOOD: U18.14 (PGOOD); also elsewhere on the board
GND: C34.2, C35.2, C36.2, C37.2, C38.2, C39.2, C40.2, C42.2, C43.2, C44.2, C45.2, C46.2, C47.2, C48.2, D11.2 (A), D12.2 (A), J8.3, J8.4, R25.2, R27.1, R29.1, R33.2, R34.2, U18.3 (PGND), U18.13 (PGND), U18.16 (AGND), U18.25 (AGND), U19.1 (GND); also elsewhere on the board
unnamed: C41.1, R31.2

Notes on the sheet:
We want a low breakdown voltage here, "normal" 5V tvs diodes will protect too late Must breakdown at ~6V to even have a _chance_ This is bogus though, no part will be able to handle the current here, I think we should just drop this
jumper to disable?
6-24V DC input. 6 DS ports * 1A * 5V = ~30W supply Regulated 5V output is provided back out on pins. If you're adventurous you can supply there instead...
Shame....... Put a SE5120ST33 here instead of the x1117 and you can kill the queiescent current
mode1: 100k for 500kHz, 200k for 750kHz, 500k for 1MHz mode2: 100k for OCP at 9.7A, 200k for OCP at 14A, 500k for OCP at 18A. Mode1 to ground: skip, to vdd:forced ccm Mode2 to ground: Softstart=3ms, to vdd, 6ms Conclusion: default SS 3ms, skip mode, 1MHz, OCP at 14A
73.2k=> 4.93 out 75k => 5.1 out... better... I think.
Need as much as 460mA at 3.3V for 7xHS ports enabled!
DS says COUT = 47 μF x 7 (329uF), CIN = 10 μF x 6, "unless otherwise noted" (for specs!) eval board hsa 3x22uF+100nF on in and 2x22uF+100nF on output ds has 2x22uF+100nf on input, plus 4x47uF on output?! perhaps, 4x10uF? for 4x10uF for 30V+ is
V_{ds} >= 30V, Imax >= 8A or so
Lol, no, there's enough caps going around
evb has 0 here for phase!
We're just trying to avoid the V_{GS} 20V limit being hit while attempting to keep it "well on" This works fine...
ds says 2.2 and 4.7, diff places evb has 1u 1u is _great_ for bom
It's suggested that 30V is too low for 24V reverse pol prot. Perhaps, DPAK? many big fat options there? NCE60P25K NCE60P50K NCE01P18K IRFR9024NTRPBF IRFR5410TRPBF IRFR5305TRPBF NCE40P70K WSF15P10
Yes, no net tie. See the datasheet, they want a single pour connecting them, even though they talk about splitting the ground plane on inner/lower layers for isolation...
5.08mm pluggable WJ2EDGRC-5.08-6P or Phoenix MSTBA fatter than needed, but good for fat fingers and low v drop

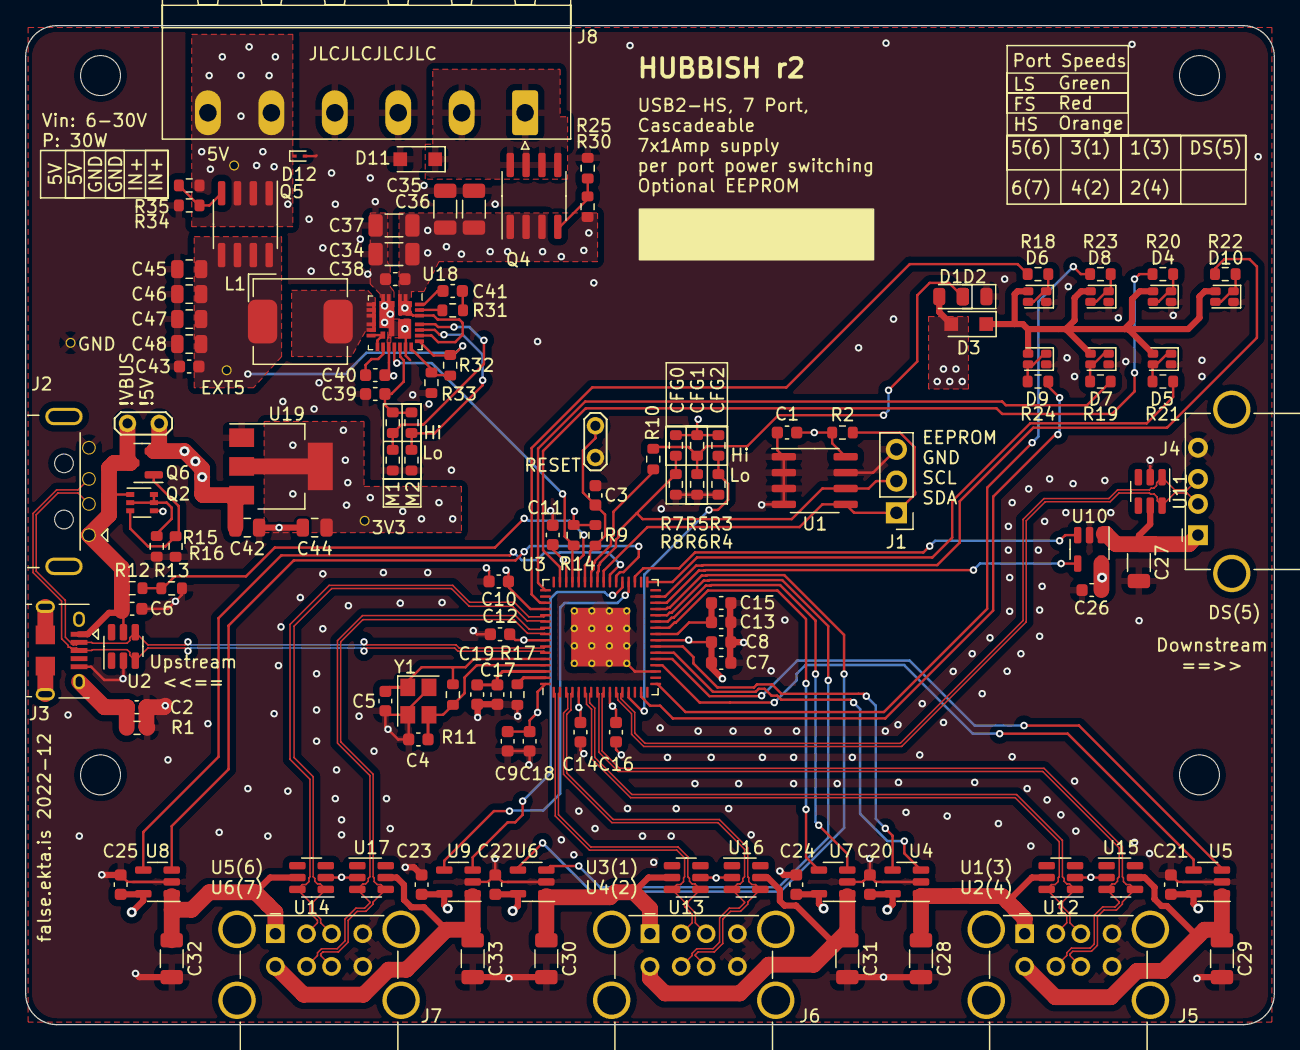
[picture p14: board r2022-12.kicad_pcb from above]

Board: 4 copper layers, 100.0 x 80.0 mm, 138 parts (0 on the bottom side), 86 nets.

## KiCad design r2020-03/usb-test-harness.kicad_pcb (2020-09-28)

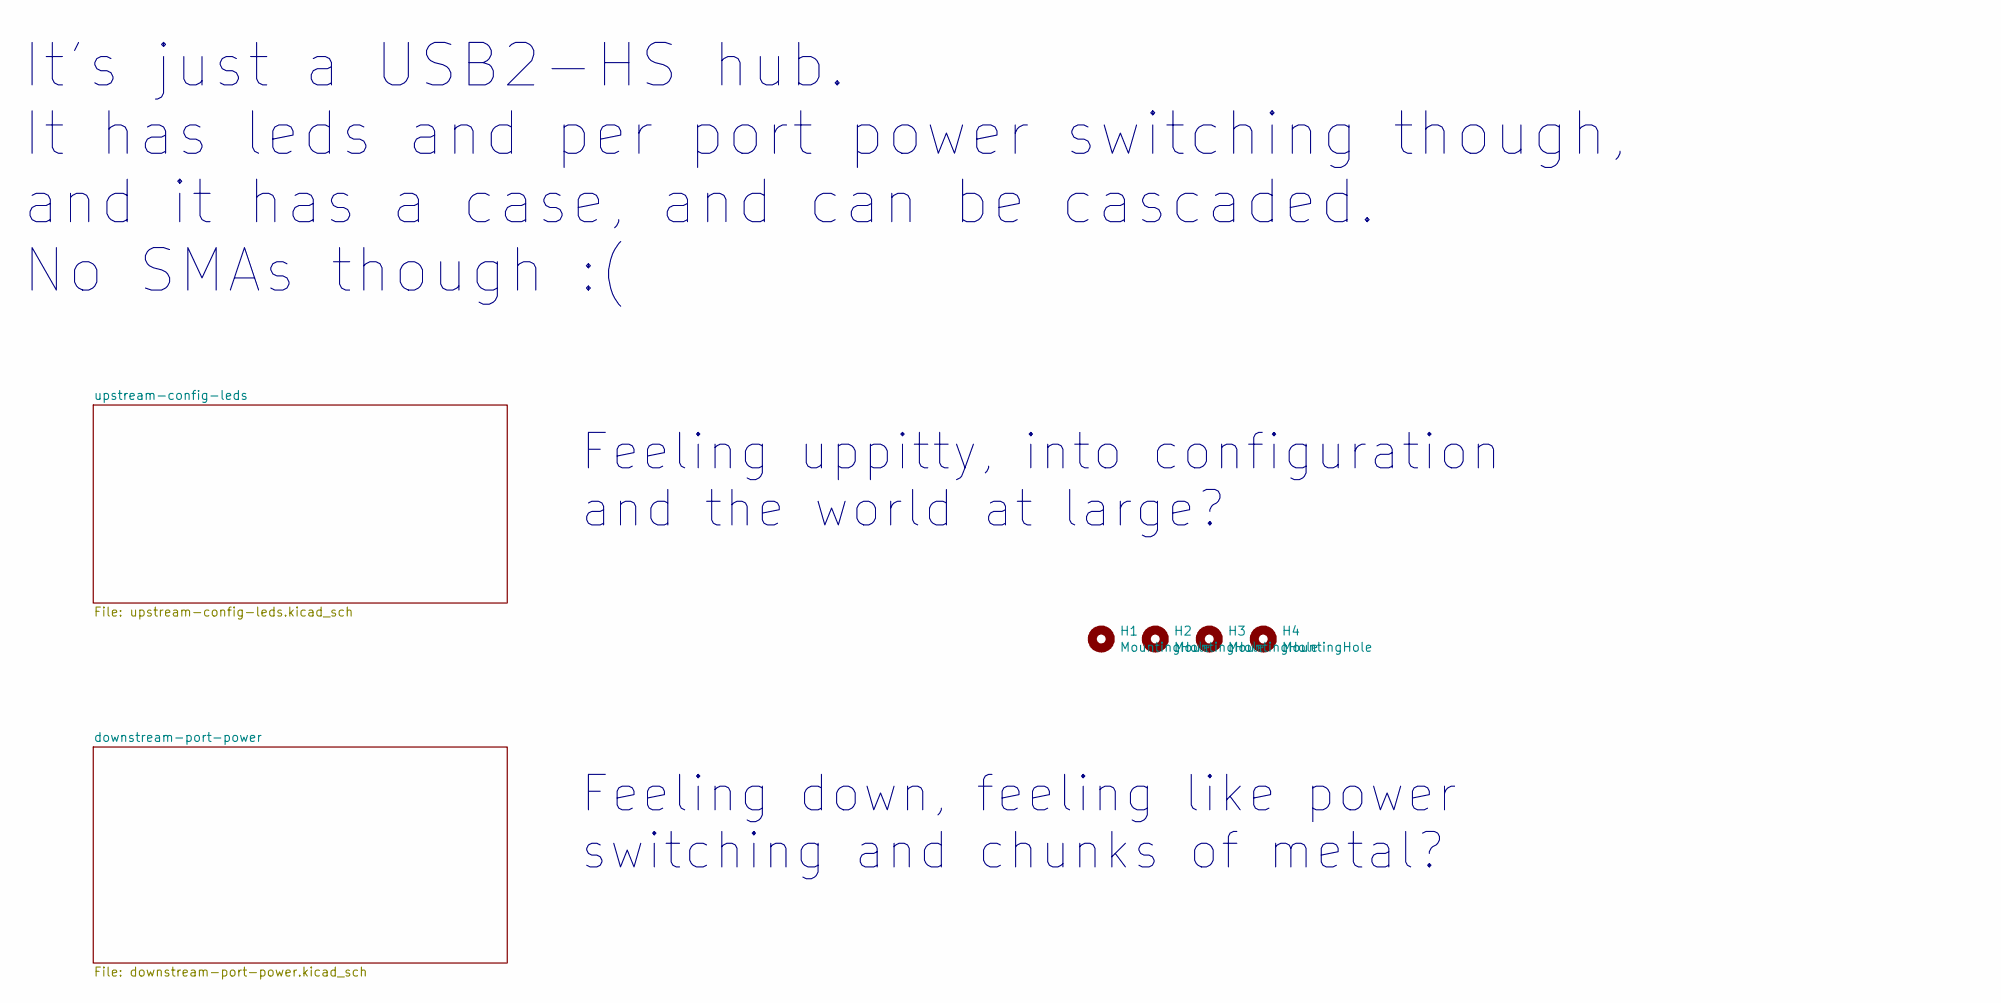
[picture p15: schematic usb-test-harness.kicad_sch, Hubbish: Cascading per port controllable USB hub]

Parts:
H1, H2, H3, H4: MountingHole; MountingHole_2.7mm_M2.5

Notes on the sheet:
It's just a USB2-HS hub. It has leds and per port power switching though, and it has a case, and can be cascaded. No SMAs though :(
Feeling uppitty, into configuration and the world at large?
Feeling down, feeling like power switching and chunks of metal?

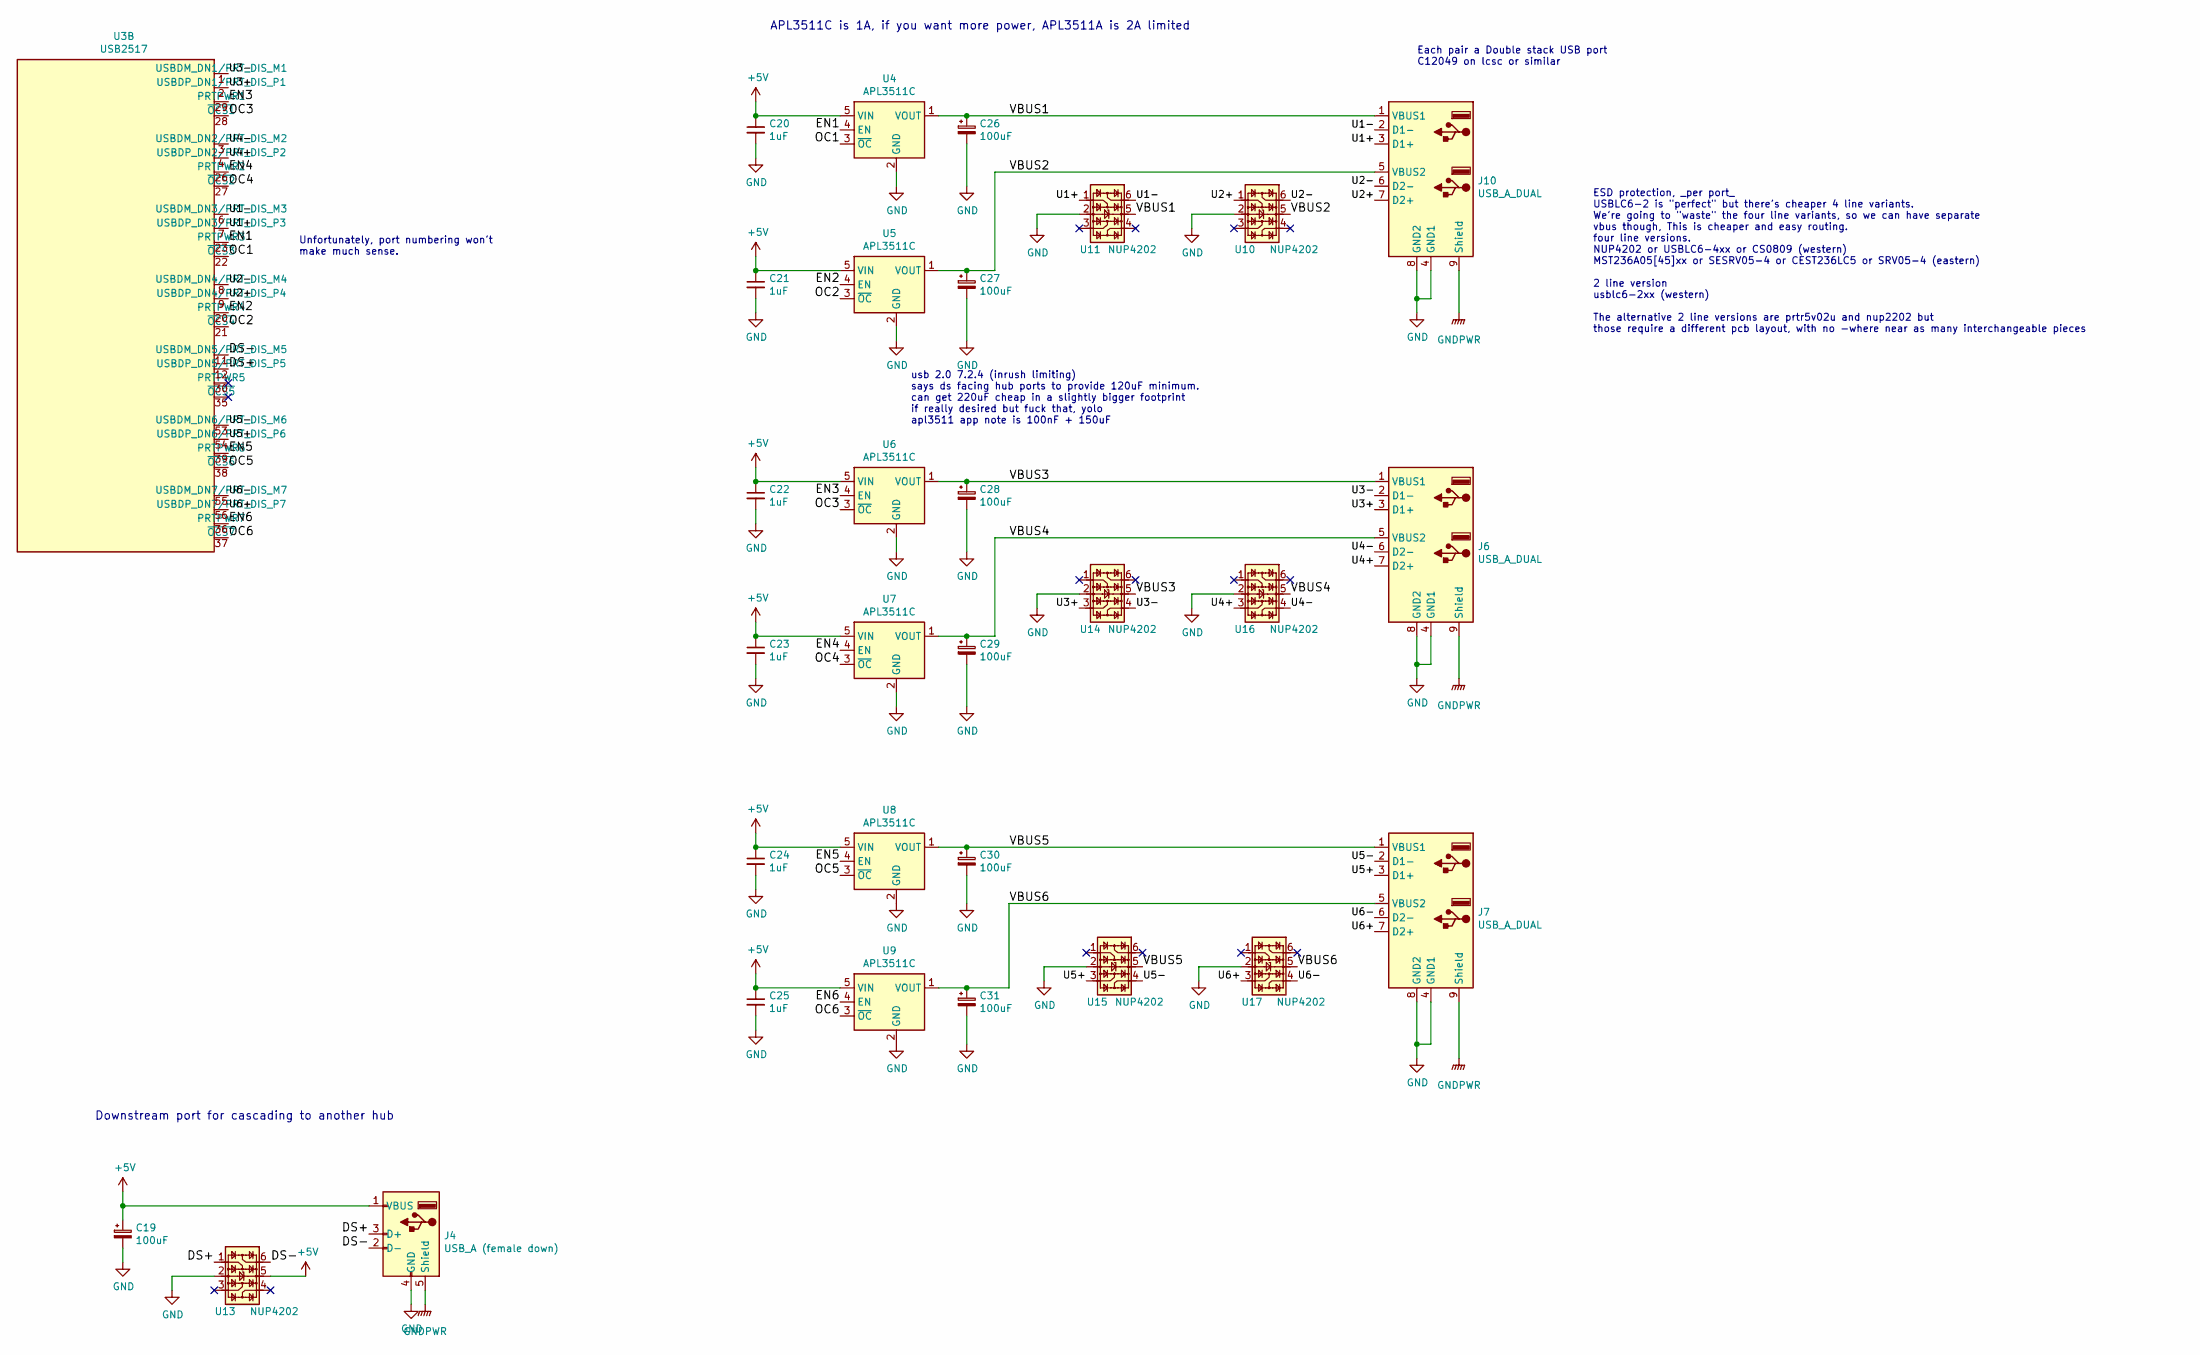
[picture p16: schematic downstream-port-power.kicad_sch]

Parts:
C19, C26, C27, C28, C29, C30, C31: 100uF; CP_Elec_5x5.4
C20, C21, C22, C23, C24, C25: 1uF; C_0603_1608Metric
J4: USB_A (female down); USB_A_Stewart_SS-52100-001_Horizontal; MPN C42643 or SS-52100 compatible
J6, J7, J10: USB_A_DUAL; USB_A_Wuerth_61400826021_Horizontal_Stacked
U3: USB2517; QFN-64-1EP_9x9mm_P0.5mm_EP4.7x4.7mm_ThermalVias
U4, U5, U6, U7, U8, U9: APL3511C; SOT-23-5
U10, U11, U13, U14, U15, U16, U17: NUP4202; SOT-23-6

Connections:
+5V: C19.1, C20.1, C21.1, C22.1, C23.1, C24.1, C25.1, J4.1 (VBUS), U4.5 (VIN), U5.5 (VIN), U6.5 (VIN), U7.5 (VIN), U8.5 (VIN), U9.5 (VIN), U13.5; also elsewhere on the board
/downstream-port-power/DS+: J4.3 (D+), U3.12 (USBDP_DN5/PRT_DIS_P5), U13.1
/downstream-port-power/DS-: J4.2 (D-), U3.11 (USBDM_DN5/PRT_DIS_M5), U13.6
/downstream-port-power/EN1: U3.23 (PRTPWR3), U4.4 (EN)
/downstream-port-power/EN2: U3.20 (PRTPWR4), U5.4 (EN)
/downstream-port-power/EN3: U3.29 (PRTPWR1), U6.4 (EN)
/downstream-port-power/EN4: U3.26 (PRTPWR2), U7.4 (EN)
/downstream-port-power/EN5: U3.39 (PRTPWR6), U8.4 (EN)
/downstream-port-power/EN6: U3.36 (PRTPWR7), U9.4 (EN)
/downstream-port-power/OC1: U3.22 (~OCS3), U4.3 (~OC)
/downstream-port-power/OC2: U3.21 (~OCS4), U5.3 (~OC)
/downstream-port-power/OC3: U3.28 (~OCS1), U6.3 (~OC)
/downstream-port-power/OC4: U3.27 (~OCS2), U7.3 (~OC)
/downstream-port-power/OC5: U3.38 (~OCS6), U8.3 (~OC)
/downstream-port-power/OC6: U3.37 (~OCS7), U9.3 (~OC)
/downstream-port-power/U1+: J10.3 (D1+), U3.7 (USBDP_DN3/PRT_DIS_P3), U11.1
/downstream-port-power/U1-: J10.2 (D1-), U3.6 (USBDM_DN3/PRT_DIS_M3), U11.6
/downstream-port-power/U2+: J10.7 (D2+), U3.9 (USBDP_DN4/PRT_DIS_P4), U10.1
/downstream-port-power/U2-: J10.6 (D2-), U3.8 (USBDM_DN4/PRT_DIS_M4), U10.6
/downstream-port-power/U3+: J6.3 (D1+), U3.2 (USBDP_DN1/PRT_DIS_P1), U14.3
/downstream-port-power/U3-: J6.2 (D1-), U3.1 (USBDM_DN1/PRT_DIS_M1), U14.4
/downstream-port-power/U4+: J6.7 (D2+), U3.4 (USBDP_DN2/PRT_DIS_P2), U16.3
/downstream-port-power/U4-: J6.6 (D2-), U3.3 (USBDM_DN2/PRT_DIS_M2), U16.4
/downstream-port-power/U5+: J7.3 (D1+), U3.54 (USBDP_DN6/PRT_DIS_P6), U15.3
/downstream-port-power/U5-: J7.2 (D1-), U3.53 (USBDM_DN6/PRT_DIS_M6), U15.4
/downstream-port-power/U6+: J7.7 (D2+), U3.56 (USBDP_DN7/PRT_DIS_P7), U17.3
/downstream-port-power/U6-: J7.6 (D2-), U3.55 (USBDM_DN7/PRT_DIS_M7), U17.4
/downstream-port-power/VBUS1: C26.1, J10.1 (VBUS1), U4.1 (VOUT), U11.5
/downstream-port-power/VBUS2: C27.1, J10.5 (VBUS2), U5.1 (VOUT), U10.5
/downstream-port-power/VBUS3: C28.1, J6.1 (VBUS1), U6.1 (VOUT), U14.5
/downstream-port-power/VBUS4: C29.1, J6.5 (VBUS2), U7.1 (VOUT), U16.5
/downstream-port-power/VBUS5: C30.1, J7.1 (VBUS1), U8.1 (VOUT), U15.5
/downstream-port-power/VBUS6: C31.1, J7.5 (VBUS2), U9.1 (VOUT), U17.5
GND: C19.2, C20.2, C21.2, C22.2, C23.2, C24.2, C25.2, C26.2, C27.2, C28.2, C29.2, C30.2, C31.2, J4.4 (GND), J6.4 (GND1), J6.8 (GND2), J7.4 (GND1), J7.8 (GND2), J10.4 (GND1), J10.8 (GND2), U4.2 (GND), U5.2 (GND), U6.2 (GND), U7.2 (GND), U8.2 (GND), U9.2 (GND), U10.2, U11.2, U13.2, U14.2, U15.2, U16.2, U17.2; also elsewhere on the board
GNDPWR: J4.5 (Shield), J6.9 (Shield), J7.9 (Shield), J10.9 (Shield); also elsewhere on the board

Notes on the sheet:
Downstream port for cascading to another hub
Unfortunately, port numbering won't make much sense.
APL3511C is 1A, if you want more power, APL3511A is 2A limited
usb 2.0 7.2.4 (inrush limiting) says ds facing hub ports to provide 120uF minimum. can get 220uF cheap in a slightly bigger footprint if really desired but fuck that, yolo apl3511 app note is 100nF + 150uF
Each pair a Double stack USB port C12049 on lcsc or similar
ESD protection, _per port_ USBLC6-2 is "perfect" but there's cheaper 4 line variants. We're going to "waste" the four line variants, so we can have separate vbus though, This is cheaper and easy routing. four line versions. NUP4202 or USBLC6-4xx or CS0809 (western) MST236A05[45]xx or SESRV05-4 or C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

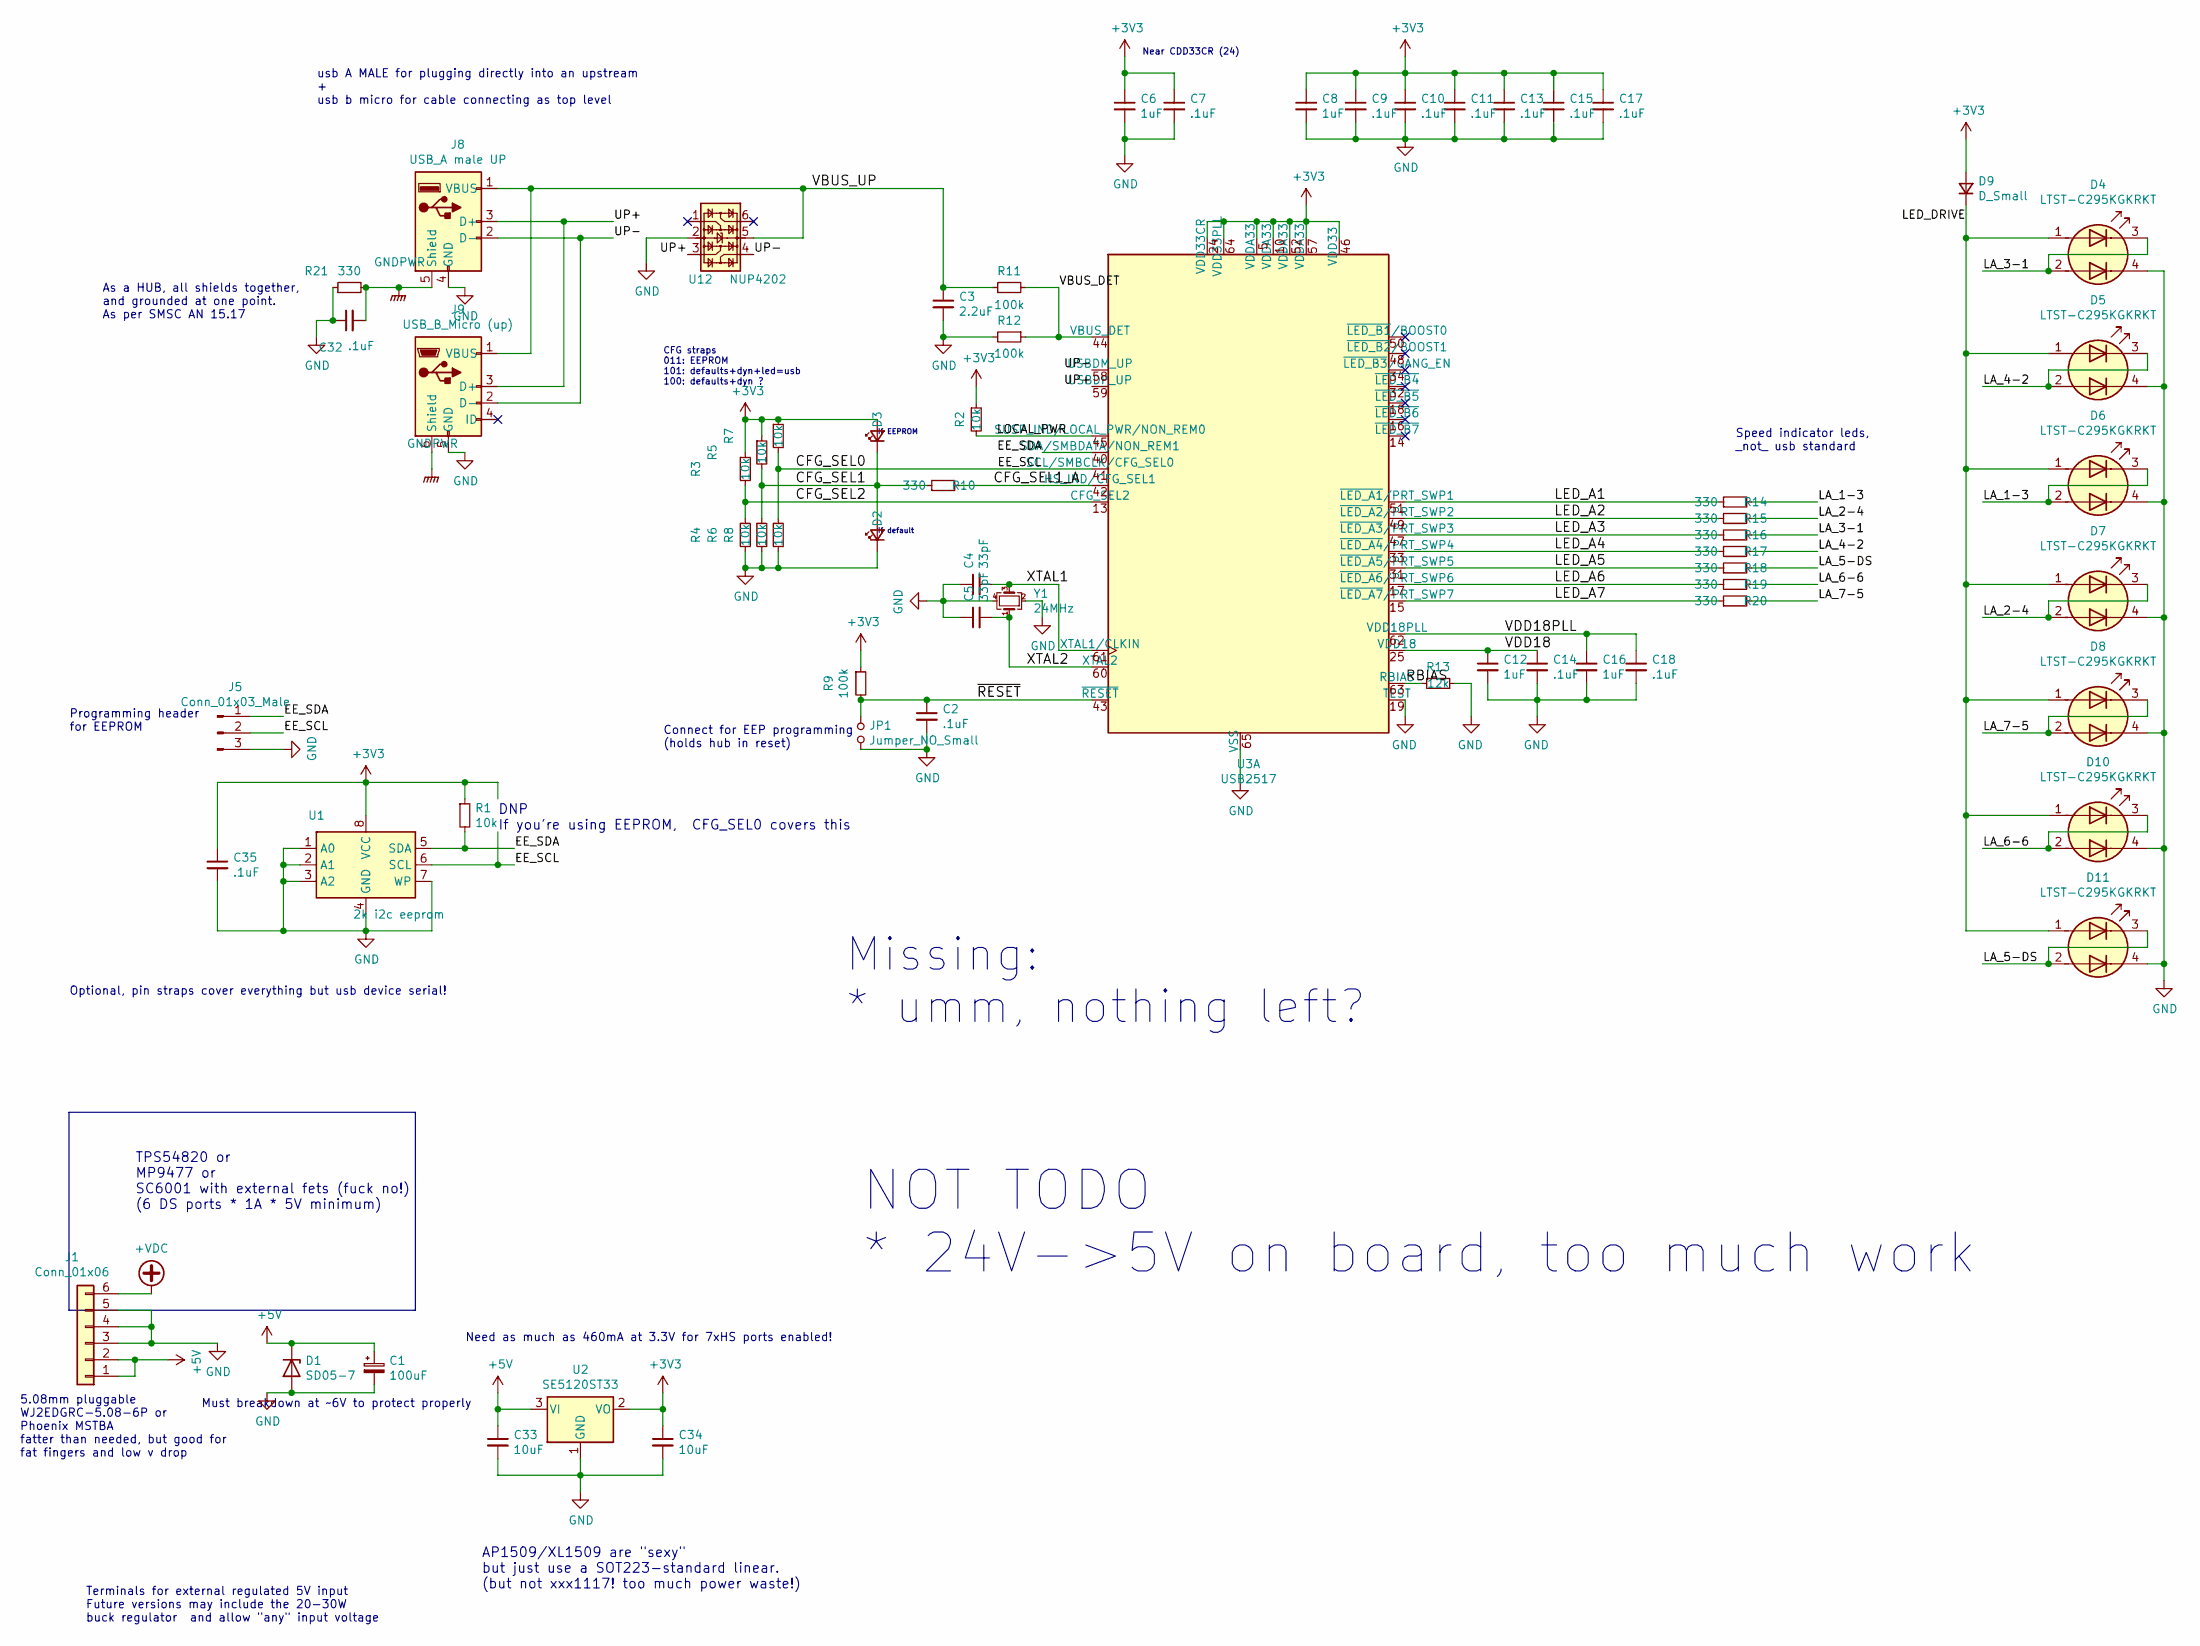
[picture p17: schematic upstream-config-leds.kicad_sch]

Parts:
C1: 100uF; CP_Elec_5x5.4
C2, C7, C9, C10, C11, C13, C14, C15, C17, C18, C32, C35: .1uF; C_0603_1608Metric
C3: 2.2uF; C_0603_1608Metric
C4, C5: 33pF; C_0603_1608Metric
C6, C8, C12, C16: 1uF; C_0603_1608Metric
C33, C34: 10uF; C_0603_1608Metric
D1: SD05-7; D_SOD-323
D2: HS1A; LED_0603_1608Metric
D3: HS1B; LED_0603_1608Metric
D4, D5, D6, D7, D8, D10, D11: LTST-C295KGKRKT; LED_LiteOn_LTST-C295K
D9: D_Small; D_SOD-323
J1: Conn_01x06; PhoenixContact_MSTBA_2,5_6-G-5,08_1x06_P5.08mm_Horizontal
J5: Conn_01x03_Male; PinHeader_1x03_P2.54mm_Vertical
J8: USB_A male UP; USB_A_Plug_SOFNG_USB-05; MPN SOFNG USB-05
J9: USB_B_Micro (up); USB_Micro-B_Amphenol_10118194-0001LF_Horizontal; MPN U254-051T-4BH23-S2B
JP1: Jumper_NO_Small; PinHeader_1x02_P2.54mm_Vertical
R1, R2, R3, R4, R5, R6, R7, R8: 10k; R_0603_1608Metric
R9, R11, R12: 100k; R_0603_1608Metric
R10, R14, R15, R16, R17, R18, R19, R20, R21: 330; R_0603_1608Metric
R13: 12k; R_0603_1608Metric
U1: 2k i2c eeprom; SOIC-8_3.9x4.9mm_P1.27mm; MPN FT24C02A
U2: SE5120ST33; SOT-223-3_TabPin2; MPN SE5120ST33
U3: USB2517; QFN-64-1EP_9x9mm_P0.5mm_EP4.7x4.7mm_ThermalVias
U12: NUP4202; SOT-363_SC-70-6
Y1: 24MHz; Crystal_SMD_3225-4Pin_3.2x2.5mm

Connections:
+3V3: C6.1, C7.1, C8.1, C9.1, C10.1, C11.1, C13.1, C15.1, C17.1, C34.1, C35.1, D3.2 (A), D9.2 (A), R1.1, R2.1, R3.1, R5.1, R7.1, R9.1, U1.8 (VCC), U2.2 (VO), U3.5 (VDDA33), U3.10 (VDDA33), U3.24 (VDD33CR), U3.46 (VDD33), U3.52 (VDDA33), U3.57 (VDDA33), U3.64 (VDD33PLL)
+5V: C1.1, C33.1, D1.1 (K), J1.1, J1.2, U2.3 (VI); also elsewhere on the board
/upstream-config-leds/CFG_SEL0: J5.2, R7.2, R8.1, U1.6 (SCL), U3.41 (SCL/SMBCLK/CFG_SEL0)
/upstream-config-leds/CFG_SEL1: D2.2 (A), D3.1 (K), R5.2, R6.1, R10.1
/upstream-config-leds/CFG_SEL1_A: R10.2, U3.42 (HS_IND/CFG_SEL1)
/upstream-config-leds/CFG_SEL2: R3.2, R4.1, U3.13 (CFG_SEL2)
/upstream-config-leds/EE_SDA: J5.1, R1.2, U1.5 (SDA), U3.40 (SDA/SMBDATA/NON_REM1)
/upstream-config-leds/LA_1-3: D6.2 (A2), D6.3 (K1), R14.2
/upstream-config-leds/LA_2-4: D7.2 (A2), D7.3 (K1), R15.2
/upstream-config-leds/LA_3-1: D4.2 (A2), D4.3 (K1), R16.2
/upstream-config-leds/LA_4-2: D5.2 (A2), D5.3 (K1), R17.2
/upstream-config-leds/LA_5-DS: D11.2 (A2), D11.3 (K1), R18.2
/upstream-config-leds/LA_6-6: D10.2 (A2), D10.3 (K1), R19.2
/upstream-config-leds/LA_7-5: D8.2 (A2), D8.3 (K1), R20.2
/upstream-config-leds/LED_A1: R14.1, U3.51 (~LED_A1~/PRT_SWP1)
/upstream-config-leds/LED_A2: R15.1, U3.49 (~LED_A2~/PRT_SWP2)
/upstream-config-leds/LED_A3: R16.1, U3.47 (~LED_A3~/PRT_SWP3)
/upstream-config-leds/LED_A4: R17.1, U3.33 (~LED_A4~/PRT_SWP4)
/upstream-config-leds/LED_A5: R18.1, U3.31 (~LED_A5~/PRT_SWP5)
/upstream-config-leds/LED_A6: R19.1, U3.17 (~LED_A6~/PRT_SWP6)
/upstream-config-leds/LED_A7: R20.1, U3.15 (~LED_A7~/PRT_SWP7)
/upstream-config-leds/LED_DRIVE: D4.1 (A1), D5.1 (A1), D6.1 (A1), D7.1 (A1), D8.1 (A1), D9.1 (K), D10.1 (A1), D11.1 (A1)
/upstream-config-leds/LOCAL_PWR: R2.2, U3.45 (SUSP_IND/LOCAL_PWR/NON_REM0)
/upstream-config-leds/RBIAS: R13.1, U3.63 (RBIAS)
/upstream-config-leds/UP+: J8.3 (D+), J9.3 (D+), U3.59 (USBDP_UP), U12.3
/upstream-config-leds/UP-: J8.2 (D-), J9.2 (D-), U3.58 (USBDM_UP), U12.4
/upstream-config-leds/VBUS_DET: R11.2, R12.1, U3.44 (VBUS_DET)
/upstream-config-leds/VBUS_UP: C3.1, J8.1 (VBUS), J9.1 (VBUS), R11.1, U12.5
/upstream-config-leds/VDD18: C12.1, C14.1, U3.25 (VDD18)
/upstream-config-leds/VDD18PLL: C16.1, C18.1, U3.62 (VDD18PLL)
/upstream-config-leds/XTAL1: C4.2, U3.61 (XTAL1/CLKIN), Y1.3
/upstream-config-leds/XTAL2: C5.2, U3.60 (XTAL2), Y1.1
/upstream-config-leds/~RESET: C2.1, JP1.1, R9.2, U3.43 (~RESET)
GND: C1.2, C2.2, C3.2, C4.1, C5.1, C6.2, C7.2, C8.2, C9.2, C10.2, C11.2, C12.2, C13.2, C14.2, C15.2, C16.2, C17.2, C18.2, C32.1, C33.2, C34.2, C35.2, D1.2 (A), D2.1 (K), D4.4 (K2), D5.4 (K2), D6.4 (K2), D7.4 (K2), D8.4 (K2), D10.4 (K2), D11.4 (K2), J1.3, J1.4, J1.5, J5.3, J8.4 (GND), J9.5 (GND), JP1.2, R4.2, R6.2, R8.2, R12.2, R13.2, R21.1, U1.1 (A0), U1.2 (A1), U1.3 (A2), U1.4 (GND), U1.7 (WP), U2.1 (GND), U3.19 (TEST), U3.65 (VSS), U12.2, Y1.2, Y1.4; also elsewhere on the board
GNDPWR: C32.2, J8.5 (Shield), J9.6 (Shield), R21.2; also elsewhere on the board

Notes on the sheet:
5.08mm pluggable WJ2EDGRC-5.08-6P or Phoenix MSTBA fatter than needed, but good for fat fingers and low v drop
Programming header for EEPROM
Optional, pin straps cover everything but usb device serial!
Terminals for external regulated 5V input Future versions may include the 20-30W buck regulator and allow "any" input voltage
As a HUB, all shields together, and grounded at one point. As per SMSC AN 15.17
TPS54820 or MP9477 or SC6001 with external fets (fuck no!) (6 DS ports * 1A * 5V minimum)
Must breakdown at ~~6V to protect properly
usb A MALE for plugging directly into an upstream + usb b micro for cable connecting as top level
Need as much as 460mA at 3.3V for 7xHS ports enabled!
AP1509/XL1509 are "sexy" but just use a SOT223-standard linear. (but not xxx1117! too much power waste!)
DNP If you're using EEPROM, CFG_SEL0 covers this
CFG straps 011: EEPROM 101: defaults+dyn+led=usb 100: defaults+dyn ?
Connect for EEP programming (holds hub in reset)
Missing: * umm, nothing left?
NOT TODO * 24V->5V on board, too much work
If EEPROM
If default
Near CDD33CR (24)
Speed indicator leds, _not_ usb standard

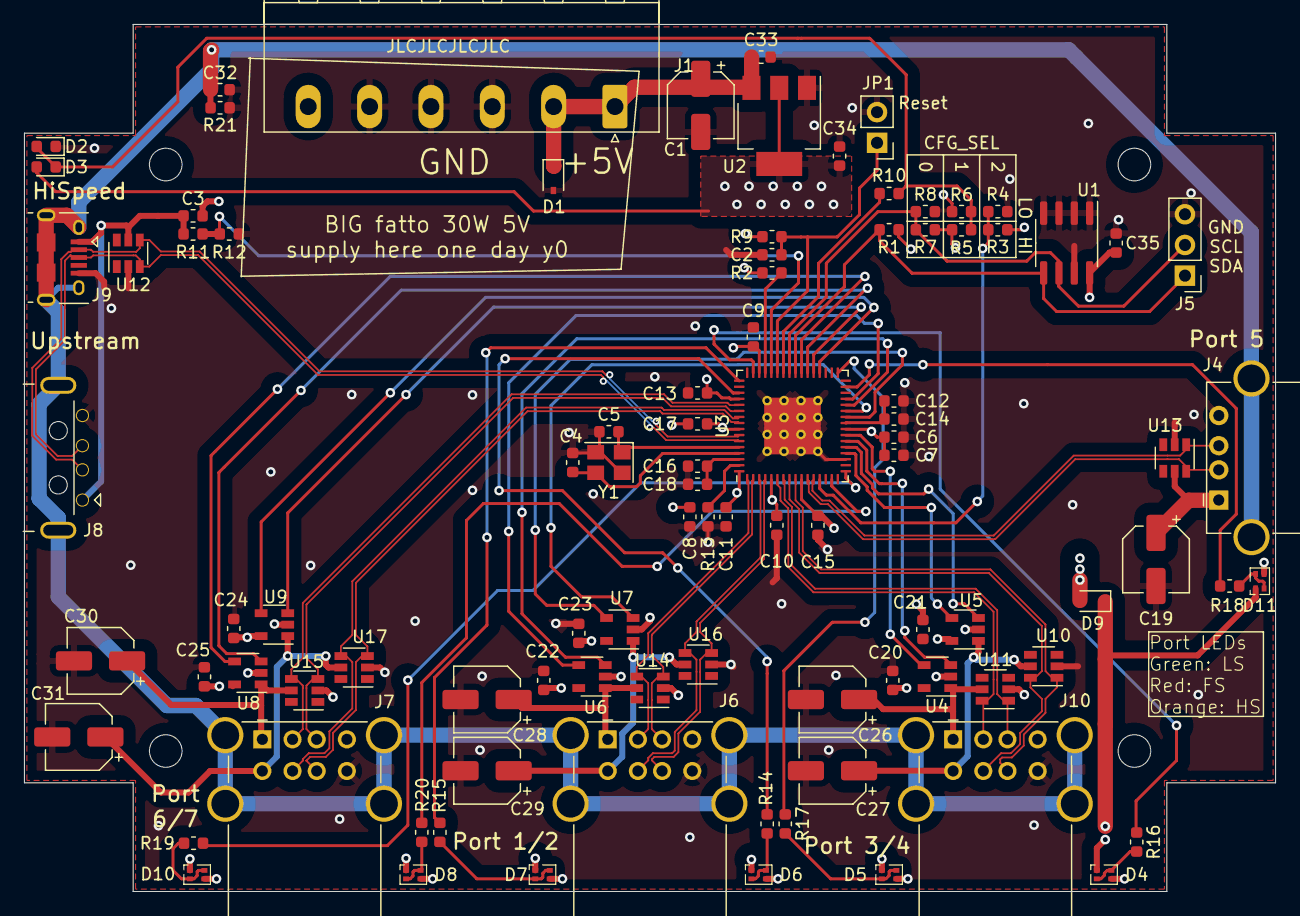
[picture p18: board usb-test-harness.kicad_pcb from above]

Board: 4 copper layers, 103.6 x 71.8 mm, 98 parts (0 on the bottom side), 67 nets.

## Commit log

2019-12-03 insane ideas on our own usb hub board
    stackable sideways to make it easier to lay out
    chainable power terminals
    dual "DUT" usb ports for discovery/etc boards with an stlink and a user
    usb port.
    [usb-test-harness.kicad_pcb, usb-test-harness.sch]
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2020-01-10 usb-test-harness: save point before refactor
    We moved to usb2517 to keep config simple, but we're about to gut the
    symbol and break the schematic apart even further.
    [usb-test-harness.sch]
2020-01-11 usb-test-harness: split hub symbol
    all night long, and we split a symbol. yay
    [downstream-port-power.sch, upstream-config-leds.sch, usb-test-harness.sch]
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2020-02-28 usb-test-harness: updated usb footprints, working on it again
    Just trying to finalise the connectors before getting down to brass
    tacks
    [downstream-port-power.sch, upstream-config-leds.sch, usb-test-harness.kicad_pcb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]
2020-03-07 usb hub: choose a box, redraw frame
    Closer and closer
    Now we have an enclosure: https://www.tme.eu/is/en/details/abs-35/enclosures-with-panel/maszczyk/km-35-gy/
    Set up the holes and outline properly. Now we can really get started.
    [downstream-port-power.sch, upstream-config-leds.sch, usb-test-harness.kicad_pcb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]
2020-03-08 hub: we've chosen leds poorly.
    We can't _really_ get away with using two discrete leds to try and get a
    bicolour effect, it's just going to be weird.
    A side mount bi colour independent woudl be good, but cant' find one
    cheaply, and top mount will be fine I think....
    [upstream-config-leds.sch]
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2020-03-10 usb-hub: pickd SOD-123F as footprint for diodes
    SMA is very common, but bigger, SOD-123F is just as cheap, and more than
    suitable.
    [upstream-config-leds.sch]
2020-03-10 usb-hub: pcb: precisely layout all the connectors again
    lock them in place, properly even and nice and clean now. Now you can
    _really_ start routing.
    [usb-test-harness.kicad_pcb]
2020-03-11 usb-hub: switch to newer amphenol micro b
    this makes it feasible to route usb properly. Then, charge ahead with
    routing. Started with the 3v3 and hub power parts, now continuing with
    the enable/overcurrent parts. leds will be last.
    [upstream-config-leds.sch, usb-test-harness.kicad_pcb]
2020-03-11 usb-hub: finish all enable/oc lines, fix warnings
    just leds, led drive, usb shields, and the big 5v mainline left.
    [usb-test-harness.kicad_pcb]
2020-03-11 usb-hub: fix broken diff pair after push n shove
    [usb-test-harness.kicad_pcb]
2020-03-11 usb-hub: fix more diff pairs broken by moving things.
    [usb-test-harness.kicad_pcb]
2020-03-13 usb-hub: just shields and silk left.
    finished all the leds and controls
    [usb-test-harness.kicad_pcb]
2020-03-13 usb-hub: add local power connection
    Somehow felt that "dynamic power" was going to magically save things
    here. It does not! required a bit of re-routing.
    [downstream-port-power.sch, upstream-config-leds.sch, usb-test-harness.kicad_pcb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]
2020-03-13 usb-hub: expand spacing on top ground
    cypress design guide, try not to have same plane ground too close to
    d+/d- traces
    [usb-test-harness.kicad_pcb]
2020-03-14 usb-hub: decide shields per app note
    SMSC 15.17 guidelines for usb hubs seem sensible and relevant.
    Connect all the shields together, and to ground at one point.
    [downstream-port-power.sch, upstream-config-leds.sch, usb-test-harness.kicad_pcb]
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2020-03-20 usb-hub: sch notes on todo, esd protection and inrush
    pcb only had silk pushing i think. kicad nightlies are trashing diffs
    :|
    [downstream-port-power.sch, upstream-config-leds.sch, usb-test-harness.kicad_pcb]
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2020-03-23 updates: bits
    * add in/out caps on 3v3 supply (how was that missed?)
    * switch to pluggable terminal blocks. better forr case design, better
    for humans, ~same price
    * added more notes on suitable esd protection on usb
    * still no input protection on 5v.
    * Added the stupid mounting hole that ruins it all with the current
    chosen case.
    [downstream-port-power.sch, upstream-config-leds.sch, usb-test-harness.kicad_pcb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]
2020-03-25 last update before changing box design
    original box is lovely, and cheap, but only available on TME, so we've
    found a new box, Bud CU-388, available on dk and mouser as well, at a
    nearly as good price.
    [upstream-config-leds.sch, usb-test-harness.kicad_pcb]
2020-03-25 enclosures: add Bud CU-388 docs
    step file was emailed on request from bud, no license attached. dxf and
    pdf are from their website.
    [bud-CU-388.STEP, bud-hb388.dxf]
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2020-04-25 Added esd protection.
    Still haven't re-routed the upstream side yet, but nearly.
    [downstream-port-power.sch, upstream-config-leds.sch, usb-test-harness.kicad_pcb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]
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2020-06-24 pcb: expand usb hub vias to 0.4mm for cheaper manufacturing
    also, added jlc text for pcb order number
    [usb-test-harness.kicad_pcb]
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2021-02-17 switch to upstream dual usb symbol
    less private local parts, more better.
    [downstream-port-power.kicad_sch, hubbish-rev2.kicad_sch, upstream-config-leds.kicad_sch]
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2021-03-01 r2: use a fet for polarity protection
    don't be dumb and use a schottkey, you're doing a 30W supply!
    [hubbish-rev2.kicad_sch, upstream-config-leds.kicad_sch]
2021-03-10 sch: rev2: update to latest kicad, add power flags.
    cleared all ERC errors/warnings
    [downstream-port-power.kicad_sch, hubbish-rev2.kicad_sch, upstream-config-leds.kicad_sch]
2021-03-11 rev2: start pcb work.
    Looks like lots of space on a 100mm square...
    [hubbish-rev2.kicad_pcb, hubbish-rev2.kicad_sch, upstream-config-leds.kicad_sch]
2021-12-07 hubbish 2021-2 updates
    line it up a bit better, realise parts are no longer available, start
    kidding myself I'm working on this again.
    [downstream-port-power.kicad_sch, hubbish-rev2.kicad_pcb, hubbish-rev2.kicad_sch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]
2021-12-10 r2021-02: "finish" routing
    it's kinda untidy, but it's all routed out now, except for where I need
    to replace the power supply
    [hubbish-rev2.kicad_pcb, upstream-config-leds.kicad_sch]
2021-12-28 hw-rev2: break out power input to a new sheet
    It was always a bit crowded there, and now that we need to pick new
    parts, we want a little more space...
    [downstream-port-power.kicad_sch, hubbish-rev2.kicad_pcb, hubbish-rev2.kicad_sch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]
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2022-10-22 BOM revisions for a rev3
    Probably not going to bother even assembling rev2 pcbs. Was missing
    parts, found other things that were a little non-ideal.
    Decided to start revising towards making it assembleable by JLC, so
    using super cheap parts from their basic line where possible, and
    minimizing bom items.
    [downstream-port-power.kicad_sch, hubbish-rev2.kicad_pcb, hubbish-rev2.kicad_sch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]
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2022-11-13 r3: reset port leds to be 5mm separation
    better for 3mm light pipes.
    TODO: shouldn't we move the hub indicicator led into the same block?!
    [r2022-10.kicad_pcb]
2022-11-15 r3: move hub led to same block/spacing
    also fixes up a few more traces that got missed when parts were resized
    (usb upstream side, and per port downstream power caps)
    [r2022-10.kicad_pcb]
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2022-11-20 r3: fix spaces in lcsc fields
    [power_input.kicad_sch]
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2022-12-17 rev4: minor fixes and tweaks to rev3.
    Fixed the current mirror to use a proper matched pair.
    Added polarity protection to the sic437, to stop it being backpowered
    when it's off and we have vbus only. We're trying to make sure we can
    properly indicate whether we have local power or not, and it's being
    back powered by the 5V.
    upgraded the OCP limit to 14A. We have 10A rated parts, and 2A rated
    switches, it seems unnecessary to artificially limit ourselves to 9.7A
    [downstream-port-power.kicad_sch, power_input.kicad_sch, r2022-12.kicad_pcb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]
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2023-12-21 update readme as best memory serves
    What was I thinking? why didn't I update any of this at the time?!
    [pricing-hacks-capacitors.ods]
2023-12-21 fix kicad jlc bom generator to include quantities
2023-12-21 rev3-2022-10: add fixme text on errors
    [power_input.kicad_sch, upstream-config-leds.kicad_sch]
